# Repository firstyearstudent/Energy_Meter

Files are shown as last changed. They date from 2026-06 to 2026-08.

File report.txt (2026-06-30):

Info: Processing symbol 'J2:Connector_PinHeader_2.54mm:PinHeader_1x04_P2.54mm_Horizontal'.
Info: Processing symbol 'TP8:PCM_SparkFun-Connector:TestPoint-0.5mm'.
Info: Processing symbol 'C11:Capacitor_THT:CP_Radial_D5.0mm_P2.00mm'.
Info: Processing symbol 'R19:Components_Footprint:RES_ERA8ARB203V'.
Info: Processing symbol 'R4:PCM_SparkFun-Resistor:R_0603_1608Metric'.
Info: Processing symbol 'C30:Capacitor_THT:C_Disc_D5.0mm_W2.5mm_P2.50mm'.
Info: Processing symbol 'R34:PCM_SparkFun-Resistor:R_0603_1608Metric'.
Info: Processing symbol 'C12:PCM_4ms_Capacitor:C_0603'.
Info: Processing symbol 'TP9:PCM_SparkFun-Connector:TestPoint-0.5mm'.
Info: Processing symbol 'R20:Components_Footprint:RES_ERA8ARB203V'.
Info: Processing symbol 'R3:Resistor_SMD:R_1206_3216Metric'.
Info: Processing symbol 'C31:Capacitor_THT:C_Disc_D5.0mm_W2.5mm_P2.50mm'.
Info: Processing symbol 'C13:Capacitor_SMD:C_0603_1608Metric'.
Info: Processing symbol 'C29:Capacitor_THT:C_Disc_D5.0mm_W2.5mm_P2.50mm'.
Info: Processing symbol 'TP10:PCM_SparkFun-Connector:TestPoint-0.5mm'.
Info: Processing symbol 'R21:Components_Footprint:RES_ERA8ARB203V'.
Info: Processing symbol 'R2:Resistor_SMD:R_1206_3216Metric'.
Info: Processing symbol 'R33:Resistor_THT:R_Axial_DIN0207_L6.3mm_D2.5mm_P10.16mm_Horizontal'.
Info: Processing symbol 'C14:PCM_SparkFun-Capacitor:C_0603_1608Metric'.
Info: Processing symbol 'C28:Capacitor_THT:C_Disc_D5.0mm_W2.5mm_P2.50mm'.
Info: Processing symbol 'R22:Resistor_THT:R_Axial_DIN0207_L6.3mm_D2.5mm_P10.16mm_Horizontal'.
Info: Processing symbol 'C9:Capacitor_THT:CP_Radial_D5.0mm_P2.00mm'.
Info: Processing symbol 'R16:Components_Footprint:RES_ERA8ARB203V'.
Info: Processing symbol 'U3:Package_SO:SOIC-16_3.9x9.9mm_P1.27mm'.
Info: Processing symbol 'C8:Capacitor_THT:CP_Radial_D5.0mm_P2.00mm'.
Info: Processing symbol 'R6:PCM_fab:R_1206'.
Info: Processing symbol 'C33:Components_Footprint:CAPRB250W50L400T250H550'.
Info: Processing symbol 'TP6:PCM_SparkFun-Connector:TestPoint-0.5mm'.
Info: Processing symbol 'SW2:PCM_fab:Button_CnK_PTS636.0_6x3.5mm'.
Info: Processing symbol 'R17:Components_Footprint:RES_ERA8ARB203V'.
Info: Processing symbol 'FB1:PCM_Ferrite_SMD_AKL:Ferrite_0805_2012Metric'.
Info: Processing symbol 'TP11:PCM_SparkFun-Connector:TestPoint-0.5mm'.
Info: Processing symbol 'R5:PCM_SparkFun-Resistor:R_1206_3216Metric'.
Info: Processing symbol 'U2:Package_SO:TSSOP-10_3x3mm_P0.5mm'.
Info: Processing symbol 'C32:Capacitor_THT:C_Disc_D5.0mm_W2.5mm_P2.50mm'.
Info: Processing symbol 'TP7:PCM_SparkFun-Connector:TestPoint-0.5mm'.
Info: Processing symbol 'C10:Capacitor_THT:C_Disc_D5.0mm_W2.5mm_P2.50mm'.
Info: Processing symbol 'R18:Components_Footprint:RES_ERA8ARB203V'.
Info: Processing symbol 'SW1:Button_Switch_SMD:SW_Tactile_SPST_NO_Straight_CK_PTS636Sx25SMTRLFS'.
Info: Processing symbol 'R4_Burden1:Components_Footprint:RESC3116X65N'.
Info: Processing symbol 'J1:PCM_fab:Conn_Jack_Stereo_3.5mm_CUI_SJ-3523-SMT-TR'.
Info: Processing symbol 'J7:Components_Footprint:POMONA_73096-2'.
Info: Processing symbol 'R25:Capacitor_SMD:C_0603_1608Metric'.
Info: Processing symbol 'J8:Components_Footprint:POMONA_73096-2'.
Info: Processing symbol 'TP14:PCM_SparkFun-Connector:TestPoint-0.5mm'.
Info: Processing symbol 'TP19:PCM_SparkFun-Connector:TestPoint-0.5mm'.
Info: Processing symbol 'R30:Resistor_THT:R_Axial_DIN0207_L6.3mm_D2.5mm_P10.16mm_Horizontal'.
Info: Processing symbol 'C19:Capacitor_SMD:C_0603_1608Metric'.
Info: Processing symbol 'J5:Components_Footprint:POMONA_73096-2'.
Info: Processing symbol 'C23:Capacitor_THT:C_Disc_D5.0mm_W2.5mm_P2.50mm'.
Info: Processing symbol 'R26:Resistor_THT:R_Axial_DIN0207_L6.3mm_D2.5mm_P10.16mm_Horizontal'.
Info: Processing symbol 'TP18:PCM_SparkFun-Connector:TestPoint-0.5mm'.
Info: Processing symbol 'C24:Capacitor_THT:CP_Radial_D5.0mm_P2.00mm'.
Info: Processing symbol 'C20:Capacitor_SMD:C_0603_1608Metric'.
Info: Processing symbol 'TP15:PCM_SparkFun-Connector:TestPoint-0.5mm'.
Info: Processing symbol 'R29:Resistor_THT:R_Axial_DIN0207_L6.3mm_D2.5mm_P10.16mm_Horizontal'.
Info: Processing symbol 'TP17:PCM_SparkFun-Connector:TestPoint-0.5mm'.
Info: Processing symbol 'C22:Capacitor_SMD:C_0603_1608Metric'.
Info: Processing symbol 'R27:Resistor_THT:R_Axial_DIN0207_L6.3mm_D2.5mm_P10.16mm_Horizontal'.
Info: Processing symbol 'C21:Capacitor_SMD:C_0603_1608Metric'.
Info: Processing symbol 'TP16:PCM_SparkFun-Connector:TestPoint-0.5mm'.
Info: Processing symbol 'J6:Components_Footprint:POMONA_73096-2'.
Info: Processing symbol 'C16:Capacitor_SMD:C_0603_1608Metric'.
Info: Processing symbol 'R1:Resistor_SMD:R_1206_3216Metric'.
Info: Processing symbol 'J3:PCM_SparkFun-Connector:USB-C_16'.
Info: Processing symbol 'C15:Capacitor_SMD:C_0603_1608Metric'.
Info: Processing symbol 'R32:PCM_SparkFun-Resistor:R_0603_1608Metric'.
Info: Processing symbol 'C26:Capacitor_THT:C_Disc_D5.0mm_W2.5mm_P2.50mm'.
Info: Processing symbol 'U1:Package_QFP:LQFP-48_7x7mm_P0.5mm'.
Info: Processing symbol 'R23:Resistor_THT:R_Axial_DIN0207_L6.3mm_D2.5mm_P10.16mm_Horizontal'.
Info: Processing symbol 'L1:Inductor_SMD:L_Sunlord_SWPA6028S'.
Info: Processing symbol 'TP12:PCM_SparkFun-Connector:TestPoint-0.5mm'.
Info: Processing symbol 'C1:Capacitor_SMD:C_1206_3216Metric'.
Info: Processing symbol 'TP21:PCM_SparkFun-Connector:TestPoint-0.5mm'.
Info: Processing symbol 'C25:Capacitor_THT:C_Disc_D5.0mm_W2.5mm_P2.50mm'.
Info: Processing symbol 'R24:Resistor_THT:R_Axial_DIN0207_L6.3mm_D2.5mm_P10.16mm_Horizontal'.
Info: Processing symbol 'J9:PCM_SparkFun-Connector:ScrewTerminal_1x02_P3.5mm_Horizontal_Black'.
Info: Processing symbol 'C17:Capacitor_SMD:C_0603_1608Metric'.
Info: Processing symbol 'R31:Resistor_THT:R_Axial_DIN0207_L6.3mm_D2.5mm_P10.16mm_Horizontal'.
Info: Processing symbol 'TP13:PCM_SparkFun-Connector:TestPoint-0.5mm'.
Info: Processing symbol 'TP20:PCM_SparkFun-Connector:TestPoint-0.5mm'.
Info: Processing symbol 'C18:Capacitor_SMD:C_0603_1608Metric'.
Info: Processing symbol 'TP4:PCM_SparkFun-Connector:TestPoint-0.5mm'.
Info: Processing symbol 'T1:Components_Footprint:XFMR_ZMPT101B'.
Info: Processing symbol 'R15_Shunt1:Components_Footprint:RESC6331X88N'.
Info: Processing symbol 'R11:PCM_SparkFun-Resistor:R_0603_1608Metric'.
Info: Processing symbol 'D6:PCM_Diode_SMD_AKL:D_SOD-523'.
Info: Processing symbol 'Y1:Crystal:Crystal_HC49-4H_Vertical'.
Info: Processing symbol 'TP1:PCM_SparkFun-Connector:TestPoint-0.5mm'.
Info: Processing symbol 'C2:Capacitor_SMD:C_1206_3216Metric'.
Info: Processing symbol 'C6:Capacitor_SMD:C_1206_3216Metric'.
Info: Processing symbol 'U4:Package_TO_SOT_SMD:SOT-223-3_TabPin2'.
Info: Processing symbol 'R8:Resistor_THT:R_Axial_DIN0207_L6.3mm_D2.5mm_P10.16mm_Horizontal'.
Info: Processing symbol 'TP2:PCM_SparkFun-Connector:TestPoint-0.5mm'.
Info: Processing symbol 'TP3:PCM_SparkFun-Connector:TestPoint-0.5mm'.
Info: Processing symbol 'C3:Capacitor_SMD:C_1206_3216Metric'.
Info: Processing symbol 'D1:LED_SMD:LED_1206_3216Metric'.
Info: Processing symbol 'D3:LED_SMD:LED_1206_3216Metric'.
Info: Processing symbol 'R13:PCM_SparkFun-Resistor:R_0603_1608Metric'.
Info: Processing symbol 'R9:Resistor_THT:R_Axial_DIN0207_L6.3mm_D2.5mm_P10.16mm_Horizontal'.
Info: Processing symbol 'SW4:Components_Footprint:EC11E15244G1_AAL'.
Info: Processing symbol 'R10_Burden1:Components_Footprint:RESC2012X60N'.
Info: Processing symbol 'C5:PCM_SparkFun-Capacitor:C_1210_3225Metric'.
Info: Processing symbol 'R15:Resistor_THT:R_Axial_DIN0207_L6.3mm_D2.5mm_P10.16mm_Horizontal'.
Info: Processing symbol 'DS1:Components_Footprint:MODULE_4311'.
Info: Processing symbol 'SW5:Button_Switch_THT:SW_PUSH_6mm'.
Info: Processing symbol 'R10:PCM_SparkFun-Resistor:R_0603_1608Metric'.
Info: Processing symbol 'C4:Capacitor_SMD:C_1206_3216Metric'.
Info: Processing symbol 'SW3:Button_Switch_THT:SW_Slide_SPDT_Straight_CK_OS102011MS2Q'.
Info: Processing symbol 'R14:PCM_SparkFun-Resistor:R_1206_3216Metric'.
Info: Processing symbol 'C7:Capacitor_SMD:C_1206_3216Metric'.
Info: Processing symbol 'R7:Resistor_THT:R_Axial_DIN0207_L6.3mm_D2.5mm_P10.16mm_Horizontal'.
Info: Processing symbol 'TP5:PCM_SparkFun-Connector:TestPoint-0.5mm'.
Info: Processing symbol 'D2:LED_SMD:LED_1206_3216Metric'.
Info: Processing symbol 'C35:Components_Footprint:CAPRB250W50L400T250H550'.
Info: Processing symbol 'D4:LED_SMD:LED_1206_3216Metric'.
Info: Processing symbol 'U6:Components_Footprint:SOP127P600X165-9N'.
Info: Processing symbol 'D7:PCM_Diode_SMD_AKL:D_SOD-523'.
Info: Processing symbol 'R12:PCM_SparkFun-Resistor:R_0603_1608Metric'.
Updated R31 sheetfile to 'Energy_Meter.kicad_sch'.
Updated SW5 symbol association from  to /096593e3-2328-43b2-82fb-24280b29d08e.
Updated R30 footprint filters to 'Resistor_THT:R_Axial_DIN0207_L6.3mm_D2.5mm*'.
Updated R31 unit metadata.
Connected SW4 pin C to GND.
Connected R31 pin 1 to 3.3VD.
Connected R30 pin 2 to Net-(C28-Pad2).
Connected SW4 pin E to GND.
Connected R30 pin 1 to 3.3VD.
Updated SW4 unit metadata.
Updated R31 footprint filters to 'Resistor_THT:R_Axial_DIN0207_L6.3mm_D2.5mm*'.
Updated R30 unit metadata.
Updated R31 sheetname to '/'.
Changed SW5 value from SW_PUSH_6mm to Push_Button.
Updated R31 fields.
Updated R31 symbol association from  to /9017e46f-2ed7-42f1-b664-4ba9339a6ba1.
Changed REF** reference designator to SW5.
Added R31 (footprint 'Resistor_THT:R_Axial_DIN0207_L6.3mm_D2.5mm_P10.16mm_Horizontal').
Changed REF** reference designator to R30.
Changed REF** reference designator to R31.
Changed R31 value from R_Axial_DIN0207_L6.3mm_D2.5mm_P10.16mm_Horizontal to 10k.
Connected R31 pin 2 to Net-(C30-Pad2).
Added SW5 (footprint 'Button_Switch_THT:SW_PUSH_6mm').
Add net Net-(U1-PB2).
Updated R29 fields.
Updated R29 symbol association from  to /d3790d62-b8e2-4885-a9b2-6dcfec7a4e3b.
Updated SW5 unit metadata.
Changed R29 value from R_Axial_DIN0207_L6.3mm_D2.5mm_P10.16mm_Horizontal to 10k.
Changed REF** reference designator to R29.
Added R29 (footprint 'Resistor_THT:R_Axial_DIN0207_L6.3mm_D2.5mm_P10.16mm_Horizontal').
Updated R27 unit metadata.
Connected R27 pin 2 to Net-(U1-PB2).
Added T1 (footprint 'Components_Footprint:XFMR_ZMPT101B').
Updated R29 sheetname to '/'.
Changed REF** reference designator to T1.
Changed T1 value from XFMR_ZMPT101B to ZMPT101B.
Connected R27 pin 1 to GND.
Updated R27 footprint filters to 'Resistor_THT:R_Axial_DIN0207_L6.3mm_D2.5mm*'.
Updated R27 sheetfile to 'Energy_Meter.kicad_sch'.
Updated R11 footprint filters to 'R_*'.
Updated R27 sheetname to '/'.
Updated T1 symbol association from  to /87a0423d-53e1-46c7-bd90-0382405e7eaa.
Connected SW5 pin 2 to Net-(C31-Pad2).
Updated R30 sheetname to '/'.
Updated R30 fields.
Updated R30 symbol association from  to /a338d966-6925-4aad-8e60-40405d52ac68.
Updated SW5 fields.
Updated SW5 sheetname to '/'.
Changed R30 value from R_Axial_DIN0207_L6.3mm_D2.5mm_P10.16mm_Horizontal to 10k.
Updated R32 sheetname to '/'.
Updated SW5 sheetfile to 'Energy_Meter.kicad_sch'.
Added R30 (footprint 'Resistor_THT:R_Axial_DIN0207_L6.3mm_D2.5mm_P10.16mm_Horizontal').
Updated R30 sheetfile to 'Energy_Meter.kicad_sch'.
Connected SW5 pin 1 to GND.
Connected SW5 pin 2 to Net-(C31-Pad2).
Updated R29 unit metadata.
Connected R29 pin 1 to 3.3VD.
Connected SW5 pin 1 to GND.
Connected R29 pin 2 to Net-(C29-Pad2).
Updated R29 footprint filters to 'Resistor_THT:R_Axial_DIN0207_L6.3mm_D2.5mm*'.
Updated R29 sheetfile to 'Energy_Meter.kicad_sch'.
Connected SW3 pin 2 to Net-(SW3-B).
Updated SW3 fields.
Updated SW1 sheetname to '/'.
Updated SW3 sheetname to '/'.
Updated SW1 fields.
Updated SW1 symbol association from  to /d2a9903d-55e1-423c-93b8-542035d82c9e.
Changed SW1 value from SW_Tactile_SPST_NO_Straight_CK_PTS636Sx25SMTRLFS to SW_Push.
Changed REF** reference designator to SW1.
Added SW1 (footprint 'Button_Switch_SMD:SW_Tactile_SPST_NO_Straight_CK_PTS636Sx25SMTRLFS').
Updated SW3 sheetfile to 'Energy_Meter.kicad_sch'.
Updated SW3 symbol association from  to /7dab059d-c71f-4d2d-af27-36c57973f747.
Updated R34 unit metadata.
Connected SW3 pin 1 to GND.
Connected R34 pin 1 to Net-(C31-Pad2).
Connected SW3 pin 3 to 3.3VD.
Connected R34 pin 2 to /RANGE.
Add net /RANGE.
Updated R34 footprint filters to 'R_*'.
Updated R34 sheetfile to 'Energy_Meter.kicad_sch'.
Updated R34 sheetname to '/'.
Added SW2 (footprint 'PCM_fab:Button_CnK_PTS636.0_6x3.5mm').
Updated SW2 footprint filters to '*Button?CnK*'.
Connected SW2 pin 2 to /TFT_RST.
Updated SW2 unit metadata.
Updated SW2 sheetfile to 'Energy_Meter.kicad_sch'.
Updated SW2 sheetname to '/'.
Updated SW2 fields.
Updated SW2 symbol association from  to /22db1ad1-a794-487a-9f3f-db319c2bdb46.
Changed SW2 value from Button_CnK_PTS636.0_6x3.5mm to Switch_Tactile_CnK.
Changed REF** reference designator to SW2.
Updated SW3 unit metadata.
Updated SW1 unit metadata.
Connected SW1 pin 1 to GND.
Added SW3 (footprint 'Button_Switch_THT:SW_Slide_SPDT_Straight_CK_OS102011MS2Q').
Changed REF** reference designator to SW3.
Connected SW1 pin 2 to Net-(U6-KEY).
Changed SW3 value from SW_Slide_SPDT_Straight_CK_OS102011MS2Q to SW_SPDT.
Add net Net-(U6-KEY).
Updated SW1 sheetfile to 'Energy_Meter.kicad_sch'.
Updated R32 footprint filters to 'R_*'.
Updated SW4 sheetname to '/'.
Changed REF** reference designator to R33.
Added R33 (footprint 'Resistor_THT:R_Axial_DIN0207_L6.3mm_D2.5mm_P10.16mm_Horizontal').
Updated SW4 sheetfile to 'Energy_Meter.kicad_sch'.
Updated R32 unit metadata.
Connected R32 pin 2 to /PUSH.
Updated SW4 footprint filters to 'EC11E15244G1_AAL'.
Add net /PUSH.
Connected R32 pin 1 to Net-(C30-Pad2).
Changed R33 value from R_Axial_DIN0207_L6.3mm_D2.5mm_P10.16mm_Horizontal to 10k.
Updated R32 sheetfile to 'Energy_Meter.kicad_sch'.
Connected SW4 pin B to Net-(C28-Pad2).
Connected SW2 pin 1 to GND.
Connected SW4 pin D to Net-(C30-Pad2).
Updated R32 fields.
Updated R32 symbol association from  to /95be6e3a-ffd1-4b5c-a334-f7b902966ed1.
Changed R32 value from R_0603_1608Metric to 100.
Connected SW4 pin A to Net-(C29-Pad2).
Changed REF** reference designator to R32.
Connected R33 pin 1 to 3.3VD.
Updated R34 fields.
Updated R34 symbol association from  to /fe889133-f561-4d1c-9acb-53b2d3170c92.
Changed R34 value from R_0603_1608Metric to 100.
Changed REF** reference designator to R34.
Added R34 (footprint 'PCM_SparkFun-Resistor:R_0603_1608Metric').
Added SW4 (footprint 'Components_Footprint:EC11E15244G1_AAL').
Changed REF** reference designator to SW4.
Updated R33 unit metadata.
Connected R33 pin 2 to Net-(C31-Pad2).
Added R32 (footprint 'PCM_SparkFun-Resistor:R_0603_1608Metric').
Updated R33 footprint filters to 'Resistor_THT:R_Axial_DIN0207_L6.3mm_D2.5mm*'.
Changed SW4 value from EC11E15244G1_AAL to EC11E15244G1.
Updated R33 sheetfile to 'Energy_Meter.kicad_sch'.
Updated R33 sheetname to '/'.
Updated R33 fields.
Updated SW4 symbol association from  to /1b6d3bd7-2777-49fa-b441-ffda2d95eb1e.
Updated R33 symbol association from  to /6c129086-1558-4fe3-90ed-3d314c50f6ce.
Updated SW4 fields.
Updated R15_Shunt1 sheetfile to 'Energy_Meter.kicad_sch'.
Add net Net-(R16-Pad2).
Updated R16 sheetfile to 'Energy_Meter.kicad_sch'.
Updated R16 sheetname to '/'.
Updated R16 fields.
Updated R16 symbol association from  to /d24ec295-7454-4889-8fb5-7ec9d18e970f.
Changed R16 value from RES_ERA8ARB203V to 20k_1206.
Changed REF** reference designator to R16.
Added R16 (footprint 'Components_Footprint:RES_ERA8ARB203V').
Updated R15_Shunt1 unit metadata.
Connected R15_Shunt1 pin 2 to Net-(R15_Shunt1-Pad2).
Connected R15_Shunt1 pin 1 to Net-(R14-Pad1).
Connected R16 pin 2 to Net-(R16-Pad2).
Updated R15_Shunt1 sheetname to '/'.
Updated R15_Shunt1 fields.
Updated R15_Shunt1 symbol association from  to /1717d047-043e-4354-aeb3-5077f84d7610.
Changed R15_Shunt1 value from RESC6331X88N to 0.001_1%_5W.
Changed REF** reference designator to R15_Shunt1.
Added R15_Shunt1 (footprint 'Components_Footprint:RESC6331X88N').
Updated R15 unit metadata.
Connected R15 pin 2 to /TFT_RST.
Connected R15 pin 1 to 3.3VD.
Updated R15 footprint filters to 'Resistor_THT:R_Axial_DIN0207_L6.3mm_D2.5mm*'.
Updated R15 sheetfile to 'Energy_Meter.kicad_sch'.
Connected R17 pin 1 to Net-(R17-Pad1).
Add net Net-(R18-Pad1).
Updated R18 sheetfile to 'Energy_Meter.kicad_sch'.
Updated R18 sheetname to '/'.
Updated R18 fields.
Updated R18 symbol association from  to /605f97b5-5b5a-45ac-96c2-aa8f0f7967b4.
Changed R18 value from RES_ERA8ARB203V to 20k_1206.
Changed REF** reference designator to R18.
Added R18 (footprint 'Components_Footprint:RES_ERA8ARB203V').
Updated R17 unit metadata.
Connected R17 pin 2 to Net-(R17-Pad2).
Add net Net-(R17-Pad2).
Updated R15 sheetname to '/'.
Add net Net-(R17-Pad1).
Updated R17 sheetfile to 'Energy_Meter.kicad_sch'.
Updated R17 sheetname to '/'.
Updated R17 fields.
Updated R17 symbol association from  to /32fd0044-c9a3-4c71-b9f6-3ce80c732c5d.
Changed R17 value from RES_ERA8ARB203V to 20k_1206.
Changed REF** reference designator to R17.
Added R17 (footprint 'Components_Footprint:RES_ERA8ARB203V').
Updated R16 unit metadata.
Connected R16 pin 1 to Net-(R16-Pad1).
Add net Net-(R16-Pad1).
Updated R12 sheetfile to 'Energy_Meter.kicad_sch'.
Updated R13 sheetname to '/'.
Updated R13 fields.
Updated R13 symbol association from  to /a9d84476-be1f-4ca3-b1ae-a8ff1df09574.
Changed R13 value from R_0603_1608Metric to 4.7k.
Changed REF** reference designator to R13.
Added R13 (footprint 'PCM_SparkFun-Resistor:R_0603_1608Metric').
Updated R12 unit metadata.
Connected R12 pin 2 to 3.3VD.
Connected R12 pin 1 to /SCL1.
Add net /SCL1.
Updated R12 footprint filters to 'R_*'.
Updated R13 sheetfile to 'Energy_Meter.kicad_sch'.
Updated R12 sheetname to '/'.
Updated R12 fields.
Updated R12 symbol association from  to /bd37f52b-9bcc-4cde-a85c-7b5f85427732.
Changed R12 value from R_0603_1608Metric to 4.7k.
Changed REF** reference designator to R12.
Added R12 (footprint 'PCM_SparkFun-Resistor:R_0603_1608Metric').
Updated R11 unit metadata.
Connected R11 pin 2 to 3.3VD.
Connected R11 pin 1 to /SDA1.
Add net /SDA1.
Added C1 (footprint 'Capacitor_SMD:C_1206_3216Metric').
Updated R14 sheetname to '/'.
Updated R15 fields.
Updated R15 symbol association from  to /f953d1ff-95f0-4f80-b716-6e3cc526713e.
Changed R15 value from R_Axial_DIN0207_L6.3mm_D2.5mm_P10.16mm_Horizontal to 10k.
Changed REF** reference designator to R15.
Added R15 (footprint 'Resistor_THT:R_Axial_DIN0207_L6.3mm_D2.5mm_P10.16mm_Horizontal').
Updated R14 unit metadata.
Connected R14 pin 1 to Net-(R14-Pad1).
Add net Net-(R14-Pad1).
Connected R14 pin 2 to IN-.
Updated R14 footprint filters to 'R_*'.
Updated R14 sheetfile to 'Energy_Meter.kicad_sch'.
Connected R18 pin 1 to Net-(R18-Pad1).
Updated R14 fields.
Updated R14 symbol association from  to /2ae87468-ac1b-4ef5-84e0-95d33e6e152b.
Changed R14 value from R_1206_3216Metric to 10.
Changed REF** reference designator to R14.
Added R14 (footprint 'PCM_SparkFun-Resistor:R_1206_3216Metric').
Updated R13 unit metadata.
Connected R13 pin 2 to Net-(U2-~{Alert}).
Add net Net-(U2-~{Alert}).
Connected R13 pin 1 to 3.3VD.
Updated R13 footprint filters to 'R_*'.
Updated R24 symbol association from  to /e59756a2-65bf-43f8-a926-fd39bd42aaef.
Updated R25 symbol association from  to /0994b7eb-327d-4d68-92b8-b3a5f0d73b3e.
Changed R25 value from C_0603_1608Metric to 1.5k_0603.
Changed REF** reference designator to R25.
Added R25 (footprint 'Capacitor_SMD:C_0603_1608Metric').
Updated R24 unit metadata.
Connected R24 pin 2 to ADC2.
Connected R24 pin 1 to Net-(R24-Pad1).
Updated R24 footprint filters to 'Resistor_THT:R_Axial_DIN0207_L6.3mm_D2.5mm*'.
Updated R24 sheetfile to 'Energy_Meter.kicad_sch'.
Updated R24 sheetname to '/'.
Updated R24 fields.
Updated R25 fields.
Changed R24 value from R_Axial_DIN0207_L6.3mm_D2.5mm_P10.16mm_Horizontal to 1k.
Changed REF** reference designator to R24.
Added R24 (footprint 'Resistor_THT:R_Axial_DIN0207_L6.3mm_D2.5mm_P10.16mm_Horizontal').
Updated R23 unit metadata.
Connected R23 pin 2 to Net-(C11-Pad1).
Connected R23 pin 1 to GND.
Updated R23 footprint filters to 'Resistor_THT:R_Axial_DIN0207_L6.3mm_D2.5mm*'.
Updated R23 sheetfile to 'Energy_Meter.kicad_sch'.
Updated R23 sheetname to '/'.
Updated R23 fields.
Updated R23 symbol association from  to /1a486011-ce61-4140-aede-66c9c4201624.
Updated R26 sheetname to '/'.
Updated R27 symbol association from  to /33faaad6-cd61-4112-8381-fef5d32c65cc.
Changed R27 value from R_Axial_DIN0207_L6.3mm_D2.5mm_P10.16mm_Horizontal to 10k.
Changed REF** reference designator to R27.
Added R27 (footprint 'Resistor_THT:R_Axial_DIN0207_L6.3mm_D2.5mm_P10.16mm_Horizontal').
Updated R26 unit metadata.
Connected R26 pin 1 to Net-(SW3-B).
Add net Net-(SW3-B).
Connected R26 pin 2 to Net-(U1-BOOT0).
Add net Net-(U1-BOOT0).
Updated R26 footprint filters to 'Resistor_THT:R_Axial_DIN0207_L6.3mm_D2.5mm*'.
Updated R26 sheetfile to 'Energy_Meter.kicad_sch'.
Changed R23 value from R_Axial_DIN0207_L6.3mm_D2.5mm_P10.16mm_Horizontal to 470k.
Updated R26 fields.
Updated R26 symbol association from  to /bc311083-1da1-4910-a27b-add62fe090ba.
Changed R26 value from R_Axial_DIN0207_L6.3mm_D2.5mm_P10.16mm_Horizontal to 10k.
Changed REF** reference designator to R26.
Added R26 (footprint 'Resistor_THT:R_Axial_DIN0207_L6.3mm_D2.5mm_P10.16mm_Horizontal').
Updated R25 unit metadata.
Connected R25 pin 2 to /USB_C+.
Connected R25 pin 1 to 3.3VD.
Updated R25 footprint filters to 'R_* R_*'.
Updated R25 sheetfile to 'Energy_Meter.kicad_sch'.
Updated R25 sheetname to '/'.
Connected R19 pin 2 to Net-(R17-Pad1).
Updated R20 unit metadata.
Connected R20 pin 1 to AC_L.
Connected R20 pin 2 to Net-(R18-Pad1).
Updated R20 sheetfile to 'Energy_Meter.kicad_sch'.
Updated R20 sheetname to '/'.
Updated R20 fields.
Updated R20 symbol association from  to /97534cb9-37e9-4301-bd6c-4e8089e2042e.
Changed R20 value from RES_ERA8ARB203V to 20k_1206.
Changed REF** reference designator to R20.
Added R20 (footprint 'Components_Footprint:RES_ERA8ARB203V').
Updated R19 unit metadata.
Added R21 (footprint 'Components_Footprint:RES_ERA8ARB203V').
Connected R19 pin 1 to Net-(R19-Pad1).
Add net Net-(R19-Pad1).
Updated R19 sheetfile to 'Energy_Meter.kicad_sch'.
Updated R19 sheetname to '/'.
Updated R19 fields.
Updated R19 symbol association from  to /00628b0d-4290-42c4-81c8-926ae012639d.
Changed R19 value from RES_ERA8ARB203V to 20k_1206.
Changed REF** reference designator to R19.
Added R19 (footprint 'Components_Footprint:RES_ERA8ARB203V').
Updated R18 unit metadata.
Connected R18 pin 2 to Net-(R16-Pad1).
Changed REF** reference designator to R22.
Changed REF** reference designator to R23.
Added R23 (footprint 'Resistor_THT:R_Axial_DIN0207_L6.3mm_D2.5mm_P10.16mm_Horizontal').
Updated R22 unit metadata.
Connected R22 pin 2 to 3.3VA.
Connected R22 pin 1 to Net-(C11-Pad1).
Updated R22 footprint filters to 'Resistor_THT:R_Axial_DIN0207_L6.3mm_D2.5mm*'.
Updated R22 sheetfile to 'Energy_Meter.kicad_sch'.
Updated R22 sheetname to '/'.
Updated R22 fields.
Updated R22 symbol association from  to /ea44b6a0-05e6-4ffd-a8ec-0865228f4b2b.
Changed R22 value from R_Axial_DIN0207_L6.3mm_D2.5mm_P10.16mm_Horizontal to 470k.
Updated R27 fields.
Added R22 (footprint 'Resistor_THT:R_Axial_DIN0207_L6.3mm_D2.5mm_P10.16mm_Horizontal').
Updated R21 unit metadata.
Connected R21 pin 2 to Net-(R19-Pad1).
Connected R21 pin 1 to AC_N.
Updated R21 sheetfile to 'Energy_Meter.kicad_sch'.
Updated R21 sheetname to '/'.
Updated R21 fields.
Updated R21 symbol association from  to /6555944e-b537-475b-9d69-0d5021b60e56.
Changed R21 value from RES_ERA8ARB203V to 20k_1206.
Changed REF** reference designator to R21.
Connected U1 pin 40 to unconnected-(U1-PB4-Pad40).
Connected U1 pin 33 to /USB_C+.
Connected U1 pin 37 to /SWCLK.
Connected U1 pin 29 to /RANGE.
Connected U1 pin 11 to ADC2.
Connected U1 pin 21 to /SCL2.
Add net /SCL2.
Connected U1 pin 46 to /TFT_DC.
Connected U1 pin 23 to GND.
Connected U1 pin 35 to GND.
Connected U1 pin 5 to /HSE_IN.
Connected U1 pin 9 to 3.3VA.
Connected U1 pin 36 to 3.3VD.
Add net unconnected-(U1-PB4-Pad40).
Connected U1 pin 22 to /SDA2.
Add net /SDA2.
Connected U1 pin 25 to /PUSH.
Connected U1 pin 8 to GND.
Connected U1 pin 38 to unconnected-(U1-PA15-Pad38).
Add net unconnected-(U1-PA15-Pad38).
Connected U1 pin 45 to /TFT_CS.
Connected U1 pin 27 to /TFT_MISO.
Connected U1 pin 18 to unconnected-(U1-PB0-Pad18).
Add net unconnected-(U1-PB0-Pad18).
Add net unconnected-(U1-PA5-Pad15).
Connected U1 pin 20 to Net-(U1-PB2).
Connected U1 pin 19 to /TFT_BLK.
Connected U1 pin 13 to unconnected-(U1-PA3-Pad13).
Add net unconnected-(U1-PA3-Pad13).
Connected U1 pin 14 to unconnected-(U1-PA4-Pad14).
Add net unconnected-(U1-PA4-Pad14).
Connected U1 pin 16 to /EC_A.
Connected U1 pin 39 to unconnected-(U1-PB3-Pad39).
Add net unconnected-(U1-PB3-Pad39).
Connected U1 pin 17 to /EC_B.
Connected U1 pin 15 to unconnected-(U1-PA5-Pad15).
Connected U1 pin 47 to GND.
Connected U1 pin 42 to /SCL1.
Connected U1 pin 34 to /SWDIO.
Connected U1 pin 1 to 3.3VD.
Connected U1 pin 48 to 3.3VD.
Connected U1 pin 7 to /TFT_RST.
Connected U1 pin 41 to unconnected-(U1-PB5-Pad41).
Add net unconnected-(U1-PB5-Pad41).
Connected U1 pin 3 to unconnected-(U1-PC14-Pad3).
Add net unconnected-(U1-PC14-Pad3).
Connected U1 pin 6 to /HSE_OUT.
Connected U1 pin 31 to /RX.
Updated TP20 sheetname to '/'.
Updated TP21 sheetname to '/'.
Updated TP21 fields.
Updated TP21 symbol association from  to /1e7c1d3b-36c7-48c4-9730-2af50b370269.
Changed TP21 value from Val** to 0.5mm.
Changed Ref** reference designator to TP21.
Added TP21 (footprint 'PCM_SparkFun-Connector:TestPoint-0.5mm').
Updated TP20 unit metadata.
Connected TP20 pin 1 to /TX.
Add net /TX.
Updated TP20 footprint filters to 'Pin* Test*'.
Updated TP20 sheetfile to 'Energy_Meter.kicad_sch'.
Updated TP21 sheetfile to 'Energy_Meter.kicad_sch'.
Updated TP20 fields.
Updated TP20 symbol association from  to /76657602-98e6-4308-94ad-b37e04be31d4.
Changed TP20 value from Val** to 0.5mm.
Changed Ref** reference designator to TP20.
Added TP20 (footprint 'PCM_SparkFun-Connector:TestPoint-0.5mm').
Updated TP19 unit metadata.
Connected TP19 pin 1 to /RX.
Add net /RX.
Updated TP19 footprint filters to 'Pin* Test*'.
Updated TP19 sheetfile to 'Energy_Meter.kicad_sch'.
Updated TP19 sheetname to '/'.
Connected U1 pin 10 to ADC1.
Connected U1 pin 32 to /USB_C-.
Connected U1 pin 24 to 3.3VD.
Connected U1 pin 26 to /TFT_SCK.
Connected U1 pin 44 to Net-(U1-BOOT0).
Connected U1 pin 4 to unconnected-(U1-PC15-Pad4).
Add net unconnected-(U1-PC15-Pad4).
Connected U1 pin 12 to unconnected-(U1-PA2-Pad12).
Add net unconnected-(U1-PA2-Pad12).
Connected U1 pin 2 to unconnected-(U1-PC13-Pad2).
Add net unconnected-(U1-PC13-Pad2).
Connected U1 pin 43 to /SDA1.
Connected U1 pin 28 to /TFT_MOSI.
Updated U1 footprint filters to 'LQFP*7x7mm*P0.5mm*'.
Updated U1 sheetfile to 'Energy_Meter.kicad_sch'.
Updated U1 sheetname to '/'.
Updated U1 fields.
Updated U1 symbol association from  to /df958145-98bf-4436-b8b1-3f5ec85b5816.
Changed U1 value from LQFP-48_7x7mm_P0.5mm to STM32F103C8Tx.
Changed REF** reference designator to U1.
Added U1 (footprint 'Package_QFP:LQFP-48_7x7mm_P0.5mm').
Updated TP21 unit metadata.
Connected TP21 pin 1 to GND.
Updated TP21 footprint filters to 'Pin* Test*'.
Updated U4 fields.
Changed U6 value from SOP127P600X165-9N to IP5306.
Changed REF** reference designator to U6.
Added U6 (footprint 'Components_Footprint:SOP127P600X165-9N').
Updated U4 unit metadata.
Connected U4 pin 3 to 5V.
Connected U4 pin 1 to GND.
Connected U4 pin 2 to 3.3VD.
Connected U4 pin 2 to 3.3VD.
Updated U4 footprint filters to 'SOT?223*TabPin2*'.
Updated U4 sheetfile to 'Energy_Meter.kicad_sch'.
Updated U4 sheetname to '/'.
Updated U6 symbol association from  to /7fd59a5a-0f41-42be-88ef-e285028ba740.
Updated U4 symbol association from  to /fbf2f771-70e9-40ec-9f3e-84057b3e04ba.
Changed U4 value from SOT-223-3_TabPin2 to AMS1117-3.3.
Changed REF** reference designator to U4.
Added U4 (footprint 'Package_TO_SOT_SMD:SOT-223-3_TabPin2').
Updated U3 unit metadata.
Connected U3 pin 7 to unconnected-(U3-NC-Pad7).
Add net unconnected-(U3-NC-Pad7).
Connected U3 pin 16 to 3.3VD.
Connected U3 pin 4 to 3.3VD.
Connected U3 pin 15 to unconnected-(U3-R232-Pad15).
Add net unconnected-(U3-R232-Pad15).
Connected U6 pin 7 to Net-(U6-SW).
Updated Y1 unit metadata.
Connected Y1 pin 1 to /HSE_IN.
Connected Y1 pin 2 to /HSE_OUT.
Updated Y1 sheetfile to 'Energy_Meter.kicad_sch'.
Updated Y1 sheetname to '/'.
Updated Y1 fields.
Updated Y1 symbol association from  to /8b861d39-8fe3-4208-917b-d46f30b4d08a.
Changed Y1 value from Crystal_HC49-4H_Vertical to Crystal_8MHz.
Changed REF** reference designator to Y1.
Added Y1 (footprint 'Crystal:Crystal_HC49-4H_Vertical').
Updated U6 unit metadata.
Connected U3 pin 14 to unconnected-(U3-~{RTS}-Pad14).
Connected U6 pin 4 to Net-(D1-K).
Connected U6 pin 5 to Net-(U6-KEY).
Connected U6 pin 2 to Net-(D1-A).
Connected U6 pin 1 to /VBUS.
Connected U6 pin 9 to GND.
Connected U6 pin 8 to 5V.
Connected U6 pin 3 to Net-(D3-A).
Connected U6 pin 6 to /BAT.
Updated U6 sheetfile to 'Energy_Meter.kicad_sch'.
Updated U6 sheetname to '/'.
Updated U6 fields.
Connected U2 pin 9 to IN-.
Changed REF** reference designator to U3.
Added U3 (footprint 'Package_SO:SOIC-16_3.9x9.9mm_P1.27mm').
Updated U2 unit metadata.
Connected U2 pin 7 to GND.
Connected U2 pin 3 to Net-(U2-~{Alert}).
Connected U2 pin 2 to GND.
Connected U2 pin 8 to IN-.
Connected U2 pin 6 to 3.3VD.
Connected U2 pin 1 to GND.
Connected U2 pin 4 to /SDA1.
Connected U2 pin 10 to IN+.
Changed U3 value from SOIC-16_3.9x9.9mm_P1.27mm to CH340C.
Connected U2 pin 5 to /SCL1.
Updated U2 footprint filters to '*TSSOP*3x3mm?P0.5mm*'.
Updated U2 sheetfile to 'Energy_Meter.kicad_sch'.
Updated U2 sheetname to '/'.
Updated U2 fields.
Updated U2 symbol association from  to /f21c2c20-8940-4f55-b5f0-f423f46fdc72.
Changed U2 value from TSSOP-10_3x3mm_P0.5mm to INA238.
Changed REF** reference designator to U2.
Added U2 (footprint 'Package_SO:TSSOP-10_3x3mm_P0.5mm').
Updated U1 unit metadata.
Connected U1 pin 30 to /TX.
Connected U3 pin 11 to unconnected-(U3-~{RI}-Pad11).
Add net unconnected-(U3-~{RTS}-Pad14).
Connected U3 pin 1 to GND.
Connected U3 pin 13 to unconnected-(U3-~{DTR}-Pad13).
Add net unconnected-(U3-~{DTR}-Pad13).
Connected U3 pin 3 to /TX.
Connected U3 pin 2 to /RX.
Connected U3 pin 8 to unconnected-(U3-NC-Pad8).
Add net unconnected-(U3-NC-Pad8).
Connected U3 pin 5 to /USB_C+.
Connected U3 pin 9 to unconnected-(U3-~{CTS}-Pad9).
Add net unconnected-(U3-~{CTS}-Pad9).
Updated TP19 fields.
Add net unconnected-(U3-~{RI}-Pad11).
Connected U3 pin 10 to unconnected-(U3-~{DSR}-Pad10).
Add net unconnected-(U3-~{DSR}-Pad10).
Connected U3 pin 6 to /USB_C-.
Connected U3 pin 12 to unconnected-(U3-~{DCD}-Pad12).
Add net unconnected-(U3-~{DCD}-Pad12).
Updated U3 footprint filters to 'SOIC*3.9x9.9mm*P1.27mm*'.
Updated U3 sheetfile to 'Energy_Meter.kicad_sch'.
Updated U3 sheetname to '/'.
Updated U3 fields.
Updated U3 symbol association from  to /a818ab0d-8f18-48de-ae49-6ee34454573d.
Changed TP6 value from Val** to 0.5mm.
Updated TP7 symbol association from  to /55a78e85-db49-4651-8782-8550663e2d3d.
Changed TP7 value from Val** to 0.5mm.
Changed Ref** reference designator to TP7.
Added TP7 (footprint 'PCM_SparkFun-Connector:TestPoint-0.5mm').
Updated TP6 unit metadata.
Connected TP6 pin 1 to GND.
Updated TP6 footprint filters to 'Pin* Test*'.
Updated TP6 sheetfile to 'Energy_Meter.kicad_sch'.
Updated TP6 sheetname to '/'.
Updated TP6 fields.
Updated TP6 symbol association from  to /f7ee8c76-ff0c-42e0-bc54-ca6df524732b.
Updated TP7 fields.
Changed Ref** reference designator to TP6.
Added TP6 (footprint 'PCM_SparkFun-Connector:TestPoint-0.5mm').
Updated TP5 unit metadata.
Connected TP5 pin 1 to Net-(C8-Pad1).
Updated TP5 footprint filters to 'Pin* Test*'.
Updated TP5 sheetfile to 'Energy_Meter.kicad_sch'.
Updated TP5 sheetname to '/'.
Updated TP5 fields.
Updated TP5 symbol association from  to /9b9cc643-683e-44af-baca-6b984bb525c5.
Changed TP5 value from Val** to 0.5mm.
Changed Ref** reference designator to TP5.
Updated TP8 sheetfile to 'Energy_Meter.kicad_sch'.
Updated TP9 footprint filters to 'Pin* Test*'.
Updated TP9 sheetfile to 'Energy_Meter.kicad_sch'.
Updated TP9 sheetname to '/'.
Updated TP9 fields.
Updated TP9 symbol association from  to /6b77d2d3-3641-49c4-a046-67ad447594a6.
Changed TP9 value from Val** to 0.5mm.
Changed Ref** reference designator to TP9.
Added TP9 (footprint 'PCM_SparkFun-Connector:TestPoint-0.5mm').
Updated TP8 unit metadata.
Connected TP8 pin 1 to Net-(R14-Pad1).
Updated TP8 footprint filters to 'Pin* Test*'.
Added TP5 (footprint 'PCM_SparkFun-Connector:TestPoint-0.5mm').
Updated TP8 sheetname to '/'.
Updated TP8 fields.
Updated TP8 symbol association from  to /661f7ee6-b1b3-4310-b39b-aa26ec17b494.
Changed TP8 value from Val** to 0.5mm.
Changed Ref** reference designator to TP8.
Added TP8 (footprint 'PCM_SparkFun-Connector:TestPoint-0.5mm').
Updated TP7 unit metadata.
Connected TP7 pin 1 to Net-(R15_Shunt1-Pad2).
Updated TP7 footprint filters to 'Pin* Test*'.
Updated TP7 sheetfile to 'Energy_Meter.kicad_sch'.
Updated TP7 sheetname to '/'.
Updated TP1 fields.
Updated TP2 sheetname to '/'.
Updated TP2 fields.
Updated TP2 symbol association from  to /e2f025a5-778d-404c-b3a6-f643b70ebfd4.
Changed TP2 value from Val** to 0.5mm.
Changed Ref** reference designator to TP2.
Added TP2 (footprint 'PCM_SparkFun-Connector:TestPoint-0.5mm').
Updated TP1 unit metadata.
Connected TP1 pin 1 to ADC2.
Updated TP1 footprint filters to 'Pin* Test*'.
Updated TP1 sheetfile to 'Energy_Meter.kicad_sch'.
Updated TP1 sheetname to '/'.
Updated TP2 sheetfile to 'Energy_Meter.kicad_sch'.
Updated TP1 symbol association from  to /d1444b62-7913-49b8-a09c-80821ec29a46.
Changed TP1 value from Val** to 0.5mm.
Changed Ref** reference designator to TP1.
Added TP1 (footprint 'PCM_SparkFun-Connector:TestPoint-0.5mm').
Updated T1 unit metadata.
Connected T1 pin 1 to Net-(R16-Pad2).
Connected T1 pin 2 to Net-(R17-Pad2).
Connected T1 pin 3 to Net-(R24-Pad1).
Connected T1 pin 4 to Net-(C11-Pad1).
Updated T1 sheetfile to 'Energy_Meter.kicad_sch'.
Updated T1 sheetname to '/'.
Connected TP3 pin 1 to GND.
Updated TP4 unit metadata.
Connected TP4 pin 1 to ADC1.
Updated TP4 footprint filters to 'Pin* Test*'.
Updated TP4 sheetfile to 'Energy_Meter.kicad_sch'.
Updated TP4 sheetname to '/'.
Updated TP4 fields.
Updated TP4 symbol association from  to /45650551-fdd0-44ae-a3d6-2cbaee5497ab.
Changed TP4 value from Val** to 0.5mm.
Changed Ref** reference designator to TP4.
Added TP4 (footprint 'PCM_SparkFun-Connector:TestPoint-0.5mm').
Updated TP3 unit metadata.
Connected TP9 pin 1 to /SDA1.
Updated TP3 footprint filters to 'Pin* Test*'.
Updated TP3 sheetfile to 'Energy_Meter.kicad_sch'.
Updated TP3 sheetname to '/'.
Updated TP3 fields.
Updated TP3 symbol association from  to /f1f94119-a13d-4731-88ad-48124542f785.
Changed TP3 value from Val** to 0.5mm.
Changed Ref** reference designator to TP3.
Added TP3 (footprint 'PCM_SparkFun-Connector:TestPoint-0.5mm').
Updated TP2 unit metadata.
Connected TP2 pin 1 to Net-(C11-Pad1).
Updated TP2 footprint filters to 'Pin* Test*'.
Connected TP15 pin 1 to 3.3VA.
Updated TP16 unit metadata.
Connected TP16 pin 1 to 5V.
Updated TP16 footprint filters to 'Pin* Test*'.
Updated TP16 sheetfile to 'Energy_Meter.kicad_sch'.
Updated TP16 sheetname to '/'.
Updated TP16 fields.
Updated TP16 symbol association from  to /eef2fdd6-9364-4114-a990-bf4599936f6a.
Changed TP16 value from Val** to 0.5mm.
Changed Ref** reference designator to TP16.
Added TP16 (footprint 'PCM_SparkFun-Connector:TestPoint-0.5mm').
Updated TP15 unit metadata.
Added TP17 (footprint 'PCM_SparkFun-Connector:TestPoint-0.5mm').
Updated TP15 footprint filters to 'Pin* Test*'.
Updated TP15 sheetfile to 'Energy_Meter.kicad_sch'.
Updated TP15 sheetname to '/'.
Updated TP15 fields.
Updated TP15 symbol association from  to /60dcd4a4-90f6-4754-9e72-7a6e8b76b2ce.
Changed TP15 value from Val** to 0.5mm.
Changed Ref** reference designator to TP15.
Added TP15 (footprint 'PCM_SparkFun-Connector:TestPoint-0.5mm').
Updated TP14 unit metadata.
Connected TP14 pin 1 to 3.3VD.
Updated TP14 footprint filters to 'Pin* Test*'.
Changed TP18 value from Val** to 0.5mm.
Updated TP19 symbol association from  to /258e1478-4668-4c86-9635-98287a04e44f.
Changed TP19 value from Val** to 0.5mm.
Changed Ref** reference designator to TP19.
Added TP19 (footprint 'PCM_SparkFun-Connector:TestPoint-0.5mm').
Updated TP18 unit metadata.
Connected TP18 pin 1 to /BAT.
Updated TP18 footprint filters to 'Pin* Test*'.
Updated TP18 sheetfile to 'Energy_Meter.kicad_sch'.
Updated TP18 sheetname to '/'.
Updated TP18 fields.
Updated TP18 symbol association from  to /09df094c-8290-4de7-9c61-67f5fbcf7706.
Updated TP14 sheetfile to 'Energy_Meter.kicad_sch'.
Changed Ref** reference designator to TP18.
Added TP18 (footprint 'PCM_SparkFun-Connector:TestPoint-0.5mm').
Updated TP17 unit metadata.
Connected TP17 pin 1 to GND.
Updated TP17 footprint filters to 'Pin* Test*'.
Updated TP17 sheetfile to 'Energy_Meter.kicad_sch'.
Updated TP17 sheetname to '/'.
Updated TP17 fields.
Updated TP17 symbol association from  to /87fd4add-c5ad-4105-aab9-c23ca5a270ad.
Changed TP17 value from Val** to 0.5mm.
Changed Ref** reference designator to TP17.
Added TP11 (footprint 'PCM_SparkFun-Connector:TestPoint-0.5mm').
Changed Ref** reference designator to TP12.
Added TP12 (footprint 'PCM_SparkFun-Connector:TestPoint-0.5mm').
Updated TP11 unit metadata.
Connected TP11 pin 1 to 3.3VD.
Updated TP11 footprint filters to 'Pin* Test*'.
Updated TP11 sheetfile to 'Energy_Meter.kicad_sch'.
Updated TP11 sheetname to '/'.
Updated TP11 fields.
Updated TP11 symbol association from  to /f54d05ac-d193-42d7-8e33-60523b00556a.
Changed TP11 value from Val** to 0.5mm.
Changed Ref** reference designator to TP11.
Changed TP12 value from Val** to 0.5mm.
Updated TP10 unit metadata.
Connected TP10 pin 1 to /SCL1.
Updated TP10 footprint filters to 'Pin* Test*'.
Updated TP10 sheetfile to 'Energy_Meter.kicad_sch'.
Updated TP10 sheetname to '/'.
Updated TP10 fields.
Updated TP10 symbol association from  to /40bf22b9-3368-400b-bc74-7549c379b06c.
Changed TP10 value from Val** to 0.5mm.
Changed Ref** reference designator to TP10.
Added TP10 (footprint 'PCM_SparkFun-Connector:TestPoint-0.5mm').
Updated TP9 unit metadata.
Updated TP13 fields.
Updated TP14 sheetname to '/'.
Updated TP14 fields.
Updated TP14 symbol association from  to /4f326855-b9da-4d6b-8082-c055f80f8b03.
Changed TP14 value from Val** to 0.5mm.
Changed Ref** reference designator to TP14.
Added TP14 (footprint 'PCM_SparkFun-Connector:TestPoint-0.5mm').
Updated TP13 unit metadata.
Connected TP13 pin 1 to /VBUS.
Updated TP13 footprint filters to 'Pin* Test*'.
Updated TP13 sheetfile to 'Energy_Meter.kicad_sch'.
Updated TP13 sheetname to '/'.
Updated T1 fields.
Updated TP13 symbol association from  to /ccbf3232-c57a-43d1-bc3d-0d1f89b06483.
Changed TP13 value from Val** to 0.5mm.
Changed Ref** reference designator to TP13.
Added TP13 (footprint 'PCM_SparkFun-Connector:TestPoint-0.5mm').
Updated TP12 unit metadata.
Connected TP12 pin 1 to IN-.
Updated TP12 footprint filters to 'Pin* Test*'.
Updated TP12 sheetfile to 'Energy_Meter.kicad_sch'.
Updated TP12 sheetname to '/'.
Updated TP12 fields.
Updated TP12 symbol association from  to /5952231a-c603-4c76-a9a0-0e13560029ab.
Connected C22 pin 2 to GND.
Added C24 (footprint 'Capacitor_THT:CP_Radial_D5.0mm_P2.00mm').
Updated C23 unit metadata.
Connected C23 pin 1 to GND.
Connected C23 pin 2 to 3.3VA.
Updated C23 sheetfile to 'Energy_Meter.kicad_sch'.
Updated C23 sheetname to '/'.
Updated C23 fields.
Updated C23 symbol association from  to /15465e66-f655-465b-8e03-f7d215192fd5.
Changed C23 value from C_Disc_D5.0mm_W2.5mm_P2.50mm to 100nF_Ceramic.
Changed REF** reference designator to C23.
Added C23 (footprint 'Capacitor_THT:C_Disc_D5.0mm_W2.5mm_P2.50mm').
Updated C22 unit metadata.
Changed REF** reference designator to C24.
Connected C22 pin 1 to 3.3VD.
Updated C22 footprint filters to 'C_*'.
Updated C22 sheetfile to 'Energy_Meter.kicad_sch'.
Updated C22 sheetname to '/'.
Updated C22 fields.
Updated C22 symbol association from  to /fd998f8f-61a9-413d-a34b-5183592d7dd2.
Changed C22 value from C_0603_1608Metric to 1uF_0603_25V.
Changed REF** reference designator to C22.
Added C22 (footprint 'Capacitor_SMD:C_0603_1608Metric').
Updated C21 unit metadata.
Connected C21 pin 1 to GND.
Changed C25 value from C_Disc_D5.0mm_W2.5mm_P2.50mm to 100nF_Ceramic.
Updated C26 symbol association from  to /29a2a541-76a7-47e5-8784-b9ede7aa3d51.
Changed C26 value from C_Disc_D5.0mm_W2.5mm_P2.50mm to 100nF_Ceramic.
Changed REF** reference designator to C26.
Added C26 (footprint 'Capacitor_THT:C_Disc_D5.0mm_W2.5mm_P2.50mm').
Updated C25 unit metadata.
Connected C25 pin 1 to GND.
Connected C25 pin 2 to 5V.
Updated C25 sheetfile to 'Energy_Meter.kicad_sch'.
Updated C25 sheetname to '/'.
Updated C25 fields.
Updated C25 symbol association from  to /2e4b0b94-9174-43a2-8c6e-895998e1de18.
Connected C21 pin 2 to 3.3VA.
Changed REF** reference designator to C25.
Added C25 (footprint 'Capacitor_THT:C_Disc_D5.0mm_W2.5mm_P2.50mm').
Updated C24 unit metadata.
Connected C24 pin 2 to GND.
Connected C24 pin 1 to 5V.
Updated C24 footprint filters to 'Capacitor_THT:CP_Radial_D5.0mm_* Capacitor_THT:CP_Radial_D4.0mm_* Capacitor_THT:CP_Radial_D6.3mm_* Capacitor_THT:CP_Radial_D7.5mm_* Capacitor_THT:CP_Radial_D8.0mm_* Capacitor_THT:CP_Radial_D10.0mm_* Capacitor_THT:CP_Radial_D14.0mm_* Capacitor_THT:CP_Radial_D16.0mm_* Capacitor_THT:CP_Radial_D18.0mm_*'.
Updated C24 sheetfile to 'Energy_Meter.kicad_sch'.
Updated C24 sheetname to '/'.
Updated C24 fields.
Updated C24 symbol association from  to /2c59f82a-6267-468e-b971-d5179faa1ba3.
Changed C24 value from CP_Radial_D5.0mm_P2.00mm to 10uF_16V.
Updated C18 sheetfile to 'Energy_Meter.kicad_sch'.
Updated C19 sheetfile to 'Energy_Meter.kicad_sch'.
Updated C19 sheetname to '/'.
Updated C19 fields.
Updated C19 symbol association from  to /c7458abb-aa6b-42df-853d-fb25b074efbc.
Changed C19 value from C_0603_1608Metric to 100nF_0603_16V.
Changed REF** reference designator to C19.
Added C19 (footprint 'Capacitor_SMD:C_0603_1608Metric').
Updated C18 unit metadata.
Connected C18 pin 1 to 3.3VD.
Connected C18 pin 2 to GND.
Updated C18 footprint filters to 'C_*'.
Updated C19 footprint filters to 'C_*'.
Updated C18 sheetname to '/'.
Updated C18 fields.
Updated C18 symbol association from  to /2afd3478-f027-49a6-ad92-a3e880ca1bb3.
Changed C18 value from C_0603_1608Metric to 100nF_0603_16V.
Changed REF** reference designator to C18.
Added C18 (footprint 'Capacitor_SMD:C_0603_1608Metric').
Updated C17 unit metadata.
Connected C17 pin 2 to GND.
Connected C17 pin 1 to 3.3VD.
Updated C17 footprint filters to 'C_*'.
Updated C17 sheetfile to 'Energy_Meter.kicad_sch'.
Connected C20 pin 2 to GND.
Add net 3.3VA.
Updated C21 footprint filters to 'C_*'.
Updated C21 sheetfile to 'Energy_Meter.kicad_sch'.
Updated C21 sheetname to '/'.
Updated C21 fields.
Updated C21 symbol association from  to /3922e4b4-5db9-43dd-9567-e59f0d6a7122.
Changed C21 value from C_0603_1608Metric to 10nF_0603_25V.
Changed REF** reference designator to C21.
Added C21 (footprint 'Capacitor_SMD:C_0603_1608Metric').
Updated C20 unit metadata.
Connected C20 pin 1 to 3.3VD.
Updated C26 fields.
Updated C20 footprint filters to 'C_*'.
Updated C20 sheetfile to 'Energy_Meter.kicad_sch'.
Updated C20 sheetname to '/'.
Updated C20 fields.
Updated C20 symbol association from  to /1ab52a96-d202-46f8-bdbc-bca580df1a4e.
Changed C20 value from C_0603_1608Metric to 10nF_0603_25V.
Changed REF** reference designator to C20.
Added C20 (footprint 'Capacitor_SMD:C_0603_1608Metric').
Updated C19 unit metadata.
Connected C19 pin 1 to 3.3VD.
Connected C19 pin 2 to GND.
Added C33 (footprint 'Components_Footprint:CAPRB250W50L400T250H550').
Added C35 (footprint 'Components_Footprint:CAPRB250W50L400T250H550').
Updated C33 unit metadata.
Connected C33 pin 1 to /HSE_OUT.
Add net /HSE_OUT.
Connected C33 pin 2 to GND.
Updated C33 sheetfile to 'Energy_Meter.kicad_sch'.
Updated C33 sheetname to '/'.
Updated C33 fields.
Updated C33 symbol association from  to /5282df6e-b3da-4eee-b894-97895dd36dc3.
Changed C33 value from CAPRB250W50L400T250H550 to 22pF.
Changed REF** reference designator to C33.
Changed REF** reference designator to C35.
Updated C32 unit metadata.
Connected C32 pin 1 to GND.
Connected C32 pin 2 to 3.3VA.
Updated C32 sheetfile to 'Energy_Meter.kicad_sch'.
Updated C32 sheetname to '/'.
Updated C32 fields.
Updated C32 symbol association from  to /e8695f93-6a5b-4bac-85d1-9c51d3ab9c6c.
Changed C32 value from C_Disc_D5.0mm_W2.5mm_P2.50mm to 100nF_Ceramic.
Changed REF** reference designator to C32.
Added C32 (footprint 'Capacitor_THT:C_Disc_D5.0mm_W2.5mm_P2.50mm').
Updated C31 unit metadata.
Changed D1 value from LED_1206_3216Metric to Blue LED.
Added D2 (footprint 'LED_SMD:LED_1206_3216Metric').
Updated D1 unit metadata.
Connected D1 pin 2 to Net-(D1-A).
Add net Net-(D1-A).
Connected D1 pin 1 to Net-(D1-K).
Add net Net-(D1-K).
Updated D1 footprint filters to 'LED* LED_SMD:* LED_THT:*'.
Updated D1 sheetfile to 'Energy_Meter.kicad_sch'.
Updated D1 sheetname to '/'.
Updated D1 fields.
Updated D1 symbol association from  to /f0566963-24a0-4803-b19a-b51260247470.
Connected C31 pin 1 to GND.
Changed REF** reference designator to D1.
Added D1 (footprint 'LED_SMD:LED_1206_3216Metric').
Updated C35 unit metadata.
Connected C35 pin 1 to /HSE_IN.
Add net /HSE_IN.
Connected C35 pin 2 to GND.
Updated C35 sheetfile to 'Energy_Meter.kicad_sch'.
Updated C35 sheetname to '/'.
Updated C35 fields.
Updated C35 symbol association from  to /ef7a245e-a575-49bb-878a-e933d29d4a9a.
Changed C35 value from CAPRB250W50L400T250H550 to 22pF.
Updated C28 sheetfile to 'Energy_Meter.kicad_sch'.
Updated C29 sheetfile to 'Energy_Meter.kicad_sch'.
Updated C29 sheetname to '/'.
Updated C29 fields.
Updated C29 symbol association from  to /321a9ee2-1c29-4aa7-8f25-ae607ea0952d.
Changed C29 value from C_Disc_D5.0mm_W2.5mm_P2.50mm to 100nF_Ceramic.
Changed REF** reference designator to C29.
Added C29 (footprint 'Capacitor_THT:C_Disc_D5.0mm_W2.5mm_P2.50mm').
Updated C28 unit metadata.
Connected C28 pin 1 to GND.
Connected C28 pin 2 to Net-(C28-Pad2).
Add net Net-(C28-Pad2).
Connected C29 pin 1 to GND.
Updated C28 sheetname to '/'.
Updated C28 fields.
Updated C28 symbol association from  to /c2912e25-3963-4a20-97da-b8efa3f3bcac.
Changed C28 value from C_Disc_D5.0mm_W2.5mm_P2.50mm to 100nF_Ceramic.
Changed REF** reference designator to C28.
Added C28 (footprint 'Capacitor_THT:C_Disc_D5.0mm_W2.5mm_P2.50mm').
Updated C26 unit metadata.
Connected C26 pin 1 to GND.
Connected C26 pin 2 to 3.3VD.
Updated C26 sheetfile to 'Energy_Meter.kicad_sch'.
Updated C26 sheetname to '/'.
Add net Net-(C30-Pad2).
Connected C31 pin 2 to Net-(C31-Pad2).
Add net Net-(C31-Pad2).
Updated C31 sheetfile to 'Energy_Meter.kicad_sch'.
Updated C31 sheetname to '/'.
Updated C31 fields.
Updated C31 symbol association from  to /ab570e18-397b-4b50-af91-c94113e9683e.
Changed C31 value from C_Disc_D5.0mm_W2.5mm_P2.50mm to 100nF_Ceramic.
Changed REF** reference designator to C31.
Added C31 (footprint 'Capacitor_THT:C_Disc_D5.0mm_W2.5mm_P2.50mm').
Updated C30 unit metadata.
Connected C30 pin 2 to Net-(C30-Pad2).
Updated C17 sheetname to '/'.
Connected C30 pin 1 to GND.
Updated C30 sheetfile to 'Energy_Meter.kicad_sch'.
Updated C30 sheetname to '/'.
Updated C30 fields.
Updated C30 symbol association from  to /92302782-0415-4b08-9566-0049cfad93c1.
Changed C30 value from C_Disc_D5.0mm_W2.5mm_P2.50mm to 100nF_Ceramic.
Changed REF** reference designator to C30.
Added C30 (footprint 'Capacitor_THT:C_Disc_D5.0mm_W2.5mm_P2.50mm').
Updated C29 unit metadata.
Connected C29 pin 2 to Net-(C29-Pad2).
Add net Net-(C29-Pad2).
Updated C5 unit metadata.
Updated C6 unit metadata.
Connected C6 pin 1 to 5V.
Connected C6 pin 2 to GND.
Updated C6 footprint filters to 'C_*'.
Updated C6 sheetfile to 'Energy_Meter.kicad_sch'.
Updated C6 sheetname to '/'.
Updated C6 fields.
Updated C6 symbol association from  to /c19f114c-e6e0-4894-bb6b-7d2d292f3190.
Changed C6 value from C_1206_3216Metric to 22 uF.
Changed REF** reference designator to C6.
Added C6 (footprint 'Capacitor_SMD:C_1206_3216Metric').
Added C7 (footprint 'Capacitor_SMD:C_1206_3216Metric').
Connected C5 pin 1 to Net-(C5-Pad1).
Add net Net-(C5-Pad1).
Connected C5 pin 2 to GND.
Updated C5 footprint filters to 'C_*'.
Updated C5 sheetfile to 'Energy_Meter.kicad_sch'.
Updated C5 sheetname to '/'.
Updated C5 fields.
Updated C5 symbol association from  to /dc0af118-5e79-4941-8920-6deb85d35f85.
Changed C5 value from C_1210_3225Metric to 10uF.
Changed REF** reference designator to C5.
Added C5 (footprint 'PCM_SparkFun-Capacitor:C_1210_3225Metric').
Changed REF** reference designator to C8.
Added C9 (footprint 'Capacitor_THT:CP_Radial_D5.0mm_P2.00mm').
Updated C8 unit metadata.
Connected C8 pin 1 to Net-(C8-Pad1).
Add net Net-(C8-Pad1).
Connected C8 pin 2 to GND.
Updated C8 footprint filters to 'Capacitor_THT:CP_Radial_D5.0mm_* Capacitor_THT:CP_Radial_D4.0mm_* Capacitor_THT:CP_Radial_D6.3mm_* Capacitor_THT:CP_Radial_D7.5mm_* Capacitor_THT:CP_Radial_D8.0mm_* Capacitor_THT:CP_Radial_D10.0mm_* Capacitor_THT:CP_Radial_D14.0mm_* Capacitor_THT:CP_Radial_D16.0mm_* Capacitor_THT:CP_Radial_D18.0mm_*'.
Updated C8 sheetfile to 'Energy_Meter.kicad_sch'.
Updated C8 sheetname to '/'.
Updated C8 fields.
Updated C8 symbol association from  to /4f53ff08-fc1d-48af-b51b-cfc3ed2f12bc.
Changed C8 value from CP_Radial_D5.0mm_P2.00mm to 10uF_16V.
Updated C4 unit metadata.
Added C8 (footprint 'Capacitor_THT:CP_Radial_D5.0mm_P2.00mm').
Updated C7 unit metadata.
Connected C7 pin 2 to GND.
Connected C7 pin 1 to 5V.
Updated C7 footprint filters to 'C_*'.
Updated C7 sheetfile to 'Energy_Meter.kicad_sch'.
Updated C7 sheetname to '/'.
Updated C7 fields.
Updated C7 symbol association from  to /a62435fa-a2c3-4ceb-b064-31b9c3b8c45a.
Changed C7 value from C_1206_3216Metric to 22 uF.
Changed REF** reference designator to C7.
Updated C1 unit metadata.
Connected C2 pin 1 to /VBUS.
Add net /VBUS.
Connected C2 pin 2 to GND.
Updated C2 footprint filters to 'C_*'.
Updated C2 sheetfile to 'Energy_Meter.kicad_sch'.
Updated C2 sheetname to '/'.
Updated C2 fields.
Updated C2 symbol association from  to /9c145543-e300-4436-b8e6-12f65d53e1a7.
Changed C2 value from C_1206_3216Metric to 10 uF.
Changed REF** reference designator to C2.
Added C2 (footprint 'Capacitor_SMD:C_1206_3216Metric').
Updated C2 unit metadata.
Connected C1 pin 2 to GND.
Add net GND.
Connected C1 pin 1 to Net-(C1-Pad1).
Add net Net-(C1-Pad1).
Updated C1 footprint filters to 'C_*'.
Updated C1 sheetfile to 'Energy_Meter.kicad_sch'.
Updated C1 sheetname to '/'.
Updated C1 fields.
Updated C1 symbol association from  to /4c4ca0da-4f94-4fe0-9759-c5f0013ad180.
Changed C1 value from C_1206_3216Metric to 10 uF.
Changed REF** reference designator to C1.
Updated C3 unit metadata.
Connected C4 pin 1 to 5V.
Add net 5V.
Connected C4 pin 2 to GND.
Updated C4 footprint filters to 'C_*'.
Updated C4 sheetfile to 'Energy_Meter.kicad_sch'.
Updated C4 sheetname to '/'.
Updated C4 fields.
Updated C4 symbol association from  to /46750d15-e548-4dbb-80b6-7b489f7f53b5.
Changed C4 value from C_1206_3216Metric to 22 uF.
Changed REF** reference designator to C4.
Added C4 (footprint 'Capacitor_SMD:C_1206_3216Metric').
Changed REF** reference designator to C9.
Connected C3 pin 1 to /BAT.
Add net /BAT.
Connected C3 pin 2 to GND.
Updated C3 footprint filters to 'C_*'.
Updated C3 sheetfile to 'Energy_Meter.kicad_sch'.
Updated C3 sheetname to '/'.
Updated C3 fields.
Updated C3 symbol association from  to /e6b51028-2adf-4468-95eb-2f63435be06b.
Changed C3 value from C_1206_3216Metric to 10 uF.
Changed REF** reference designator to C3.
Added C3 (footprint 'Capacitor_SMD:C_1206_3216Metric').
Updated C14 sheetname to '/'.
Updated C15 symbol association from  to /75ddc3e3-4df2-40ec-b71c-87b901fafc08.
Changed C15 value from C_0603_1608Metric to 100nF_0603_16V.
Changed REF** reference designator to C15.
Added C15 (footprint 'Capacitor_SMD:C_0603_1608Metric').
Updated C14 unit metadata.
Connected C14 pin 1 to IN+.
Add net IN+.
Connected C14 pin 2 to IN-.
Add net IN-.
Updated C14 footprint filters to 'C_*'.
Updated C14 sheetfile to 'Energy_Meter.kicad_sch'.
Updated C15 fields.
Updated C14 fields.
Updated C14 symbol association from  to /e60c779c-7d28-46e2-88ee-557ea930da91.
Changed C14 value from C_0603_1608Metric to 0.1uF.
Changed REF** reference designator to C14.
Added C14 (footprint 'PCM_SparkFun-Capacitor:C_0603_1608Metric').
Updated C13 unit metadata.
Connected C13 pin 2 to GND.
Connected C13 pin 1 to 3.3VD.
Updated C13 footprint filters to 'C_*'.
Updated C13 sheetfile to 'Energy_Meter.kicad_sch'.
Updated C13 sheetname to '/'.
Updated C16 fields.
Updated C17 fields.
Updated C17 symbol association from  to /6c82aa47-69d9-4db6-97c0-2bd5995b6cea.
Changed C17 value from C_0603_1608Metric to 100nF_0603_16V.
Changed REF** reference designator to C17.
Added C17 (footprint 'Capacitor_SMD:C_0603_1608Metric').
Updated C16 unit metadata.
Connected C16 pin 1 to 3.3VD.
Connected C16 pin 2 to GND.
Updated C16 footprint filters to 'C_*'.
Updated C16 sheetfile to 'Energy_Meter.kicad_sch'.
Updated C16 sheetname to '/'.
Updated C13 fields.
Updated C16 symbol association from  to /84366609-2ca2-4785-916e-59cc60f39337.
Changed C16 value from C_0603_1608Metric to 100nF_0603_16V.
Changed REF** reference designator to C16.
Added C16 (footprint 'Capacitor_SMD:C_0603_1608Metric').
Updated C15 unit metadata.
Connected C15 pin 1 to /TFT_RST.
Add net /TFT_RST.
Connected C15 pin 2 to GND.
Updated C15 footprint filters to 'C_*'.
Updated C15 sheetfile to 'Energy_Meter.kicad_sch'.
Updated C15 sheetname to '/'.
Changed REF** reference designator to C10.
Changed C11 value from CP_Radial_D5.0mm_P2.00mm to 10uF_16V.
Changed REF** reference designator to C11.
Added C11 (footprint 'Capacitor_THT:CP_Radial_D5.0mm_P2.00mm').
Updated C10 unit metadata.
Connected C10 pin 2 to 3.3VD.
Connected C10 pin 1 to GND.
Updated C10 sheetfile to 'Energy_Meter.kicad_sch'.
Updated C10 sheetname to '/'.
Updated C10 fields.
Updated C10 symbol association from  to /1f272da7-28ad-41d6-943f-bf37fd46d00d.
Changed C10 value from C_Disc_D5.0mm_W2.5mm_P2.50mm to 100nF_Ceramic.
Updated C11 symbol association from  to /12ae69e4-3bd2-4fa9-92e7-8c2d2d82d77f.
Added C10 (footprint 'Capacitor_THT:C_Disc_D5.0mm_W2.5mm_P2.50mm').
Updated C9 unit metadata.
Connected C9 pin 1 to 3.3VD.
Add net 3.3VD.
Connected C9 pin 2 to GND.
Updated C9 footprint filters to 'Capacitor_THT:CP_Radial_D5.0mm_* Capacitor_THT:CP_Radial_D4.0mm_* Capacitor_THT:CP_Radial_D6.3mm_* Capacitor_THT:CP_Radial_D7.5mm_* Capacitor_THT:CP_Radial_D8.0mm_* Capacitor_THT:CP_Radial_D10.0mm_* Capacitor_THT:CP_Radial_D14.0mm_* Capacitor_THT:CP_Radial_D16.0mm_* Capacitor_THT:CP_Radial_D18.0mm_*'.
Updated C9 sheetfile to 'Energy_Meter.kicad_sch'.
Updated C9 sheetname to '/'.
Updated C9 fields.
Updated C9 symbol association from  to /df9c76cf-6f45-4415-9db8-4bf14a5982ac.
Changed C9 value from CP_Radial_D5.0mm_P2.00mm to 10uF_16V.
Updated C12 symbol association from  to /0741aaf9-4093-4321-93f8-180a72351281.
Updated C13 symbol association from  to /73960ead-f6f1-440d-a05d-c83e0f7719a5.
Changed C13 value from C_0603_1608Metric to 1uF_0603_25V.
Changed REF** reference designator to C13.
Added C13 (footprint 'Capacitor_SMD:C_0603_1608Metric').
Updated C12 unit metadata.
Connected C12 pin 1 to 3.3VD.
Connected C12 pin 2 to GND.
Updated C12 footprint filters to 'C_*'.
Updated C12 sheetfile to 'Energy_Meter.kicad_sch'.
Updated C12 sheetname to '/'.
Updated C12 fields.
Updated R11 sheetname to '/'.
Changed C12 value from ? to 0.1uF_0603_16V.
Changed C? reference designator to C12.
Added C12 (footprint 'PCM_4ms_Capacitor:C_0603').
Updated C11 unit metadata.
Connected C11 pin 1 to Net-(C11-Pad1).
Add net Net-(C11-Pad1).
Connected C11 pin 2 to GND.
Updated C11 footprint filters to 'Capacitor_THT:CP_Radial_D5.0mm_* Capacitor_THT:CP_Radial_D4.0mm_* Capacitor_THT:CP_Radial_D6.3mm_* Capacitor_THT:CP_Radial_D7.5mm_* Capacitor_THT:CP_Radial_D8.0mm_* Capacitor_THT:CP_Radial_D10.0mm_* Capacitor_THT:CP_Radial_D14.0mm_* Capacitor_THT:CP_Radial_D16.0mm_* Capacitor_THT:CP_Radial_D18.0mm_*'.
Updated C11 sheetfile to 'Energy_Meter.kicad_sch'.
Updated C11 sheetname to '/'.
Updated C11 fields.
Changed REF** reference designator to R2.
Changed REF** reference designator to R3.
Added R3 (footprint 'Resistor_SMD:R_1206_3216Metric').
Updated R2 unit metadata.
Connected R2 pin 2 to Net-(J3-CC1).
Connected R2 pin 1 to GND.
Updated R2 footprint filters to 'R_*'.
Updated R2 sheetfile to 'Energy_Meter.kicad_sch'.
Updated R2 sheetname to '/'.
Updated R2 fields.
Updated R2 symbol association from  to /dc6c44bd-eaa2-43b5-ab80-1ac492e876e2.
Changed R2 value from R_1206_3216Metric to 5.1K.
Changed R3 value from R_1206_3216Metric to 2Ω.
Added R2 (footprint 'Resistor_SMD:R_1206_3216Metric').
Updated R1 unit metadata.
Connected R1 pin 1 to GND.
Connected R1 pin 2 to Net-(J3-CC2).
Updated R1 footprint filters to 'R_*'.
Updated R1 sheetfile to 'Energy_Meter.kicad_sch'.
Updated R1 sheetname to '/'.
Updated R1 fields.
Updated R1 symbol association from  to /8be05807-b398-4c60-a9da-1d78f36c5e56.
Changed R1 value from R_1206_3216Metric to 5.1K.
Changed REF** reference designator to R1.
Changed R4 value from R_0603_1608Metric to 100.
Changed REF** reference designator to R4_Burden1.
Added R4_Burden1 (footprint 'Components_Footprint:RESC3116X65N').
Updated R4 unit metadata.
Connected R4 pin 1 to /EC_A.
Add net /EC_A.
Connected R4 pin 2 to Net-(C29-Pad2).
Updated R4 footprint filters to 'R_*'.
Updated R4 sheetfile to 'Energy_Meter.kicad_sch'.
Updated R4 sheetname to '/'.
Updated R4 fields.
Updated R4 symbol association from  to /8371d5e1-ec2c-49e3-be3e-1a75001ea86a.
Added R1 (footprint 'Resistor_SMD:R_1206_3216Metric').
Changed REF** reference designator to R4.
Added R4 (footprint 'PCM_SparkFun-Resistor:R_0603_1608Metric').
Updated R3 unit metadata.
Connected R3 pin 2 to Net-(C1-Pad1).
Connected R3 pin 1 to /VBUS.
Updated R3 footprint filters to 'R_*'.
Updated R3 sheetfile to 'Energy_Meter.kicad_sch'.
Updated R3 sheetname to '/'.
Updated R3 fields.
Updated R3 symbol association from  to /334df98c-6f9e-4335-8122-47fd2e279080.
Connected J7 pin 1 to IN+.
Updated J8 unit metadata.
Connected J8 pin 1 to IN-.
Updated J8 footprint filters to 'Connector*:*_1x??-1SH*'.
Updated J8 sheetfile to 'Energy_Meter.kicad_sch'.
Updated J8 sheetname to '/'.
Updated J8 fields.
Updated J8 symbol association from  to /70b5dbf1-c73e-4ddd-a099-d09b9ba34176.
Changed J8 value from POMONA_73096-2 to Conn_01x01_Shielded.
Changed REF** reference designator to J8.
Added J8 (footprint 'Components_Footprint:POMONA_73096-2').
Updated J7 unit metadata.
Added J9 (footprint 'PCM_SparkFun-Connector:ScrewTerminal_1x02_P3.5mm_Horizontal_Black').
Updated J7 footprint filters to 'Connector*:*_1x??-1SH*'.
Updated J7 sheetfile to 'Energy_Meter.kicad_sch'.
Updated J7 sheetname to '/'.
Updated J7 fields.
Updated J7 symbol association from  to /cf8ee4c5-430d-492c-81a7-2ca75d5b22b2.
Changed J7 value from POMONA_73096-2 to Conn_01x01_Shielded.
Changed REF** reference designator to J7.
Added J7 (footprint 'Components_Footprint:POMONA_73096-2').
Updated J6 unit metadata.
Connected J6 pin 1 to AC_N.
Add net AC_N.
Added L1 (footprint 'Inductor_SMD:L_Sunlord_SWPA6028S').
Updated L1 unit metadata.
Connected L1 pin 2 to /BAT.
Connected L1 pin 1 to Net-(U6-SW).
Add net Net-(U6-SW).
Updated L1 footprint filters to 'Choke_* *Coil* Inductor_* L_*'.
Updated L1 sheetfile to 'Energy_Meter.kicad_sch'.
Updated L1 sheetname to '/'.
Updated L1 fields.
Updated L1 symbol association from  to /fcd8d108-72a2-42e1-b3b8-63f80d03cc31.
Changed L1 value from L_Sunlord_SWPA6028S to 1 µH.
Changed REF** reference designator to L1.
Changed R4_Burden1 value from RESC3116X65N to 360_1206.
Updated J9 unit metadata.
Connected J9 pin 1 to /BAT.
Connected J9 pin 2 to GND.
Updated J9 footprint filters to 'TerminalBlock*:*'.
Updated J9 sheetfile to 'Energy_Meter.kicad_sch'.
Updated J9 sheetname to '/'.
Updated J9 fields.
Updated J9 symbol association from  to /7f9534b1-fdfe-4363-af77-16b92368435f.
Changed J9 value from Screw_Terminal_3.5mm-2 to 3.5mm.
Changed REF** reference designator to J9.
Updated R9 fields.
Updated R10 fields.
Updated R10 symbol association from  to /b1447d86-92c2-4260-a437-864d22c5b76b.
Changed R10 value from R_0603_1608Metric to 100.
Changed REF** reference designator to R10.
Added R10 (footprint 'PCM_SparkFun-Resistor:R_0603_1608Metric').
Updated R9 unit metadata.
Connected R9 pin 1 to Net-(J1-Pad2).
Connected R9 pin 2 to ADC1.
Updated R9 footprint filters to 'Resistor_THT:R_Axial_DIN0207_L6.3mm_D2.5mm*'.
Updated R9 sheetfile to 'Energy_Meter.kicad_sch'.
Updated R9 sheetname to '/'.
Updated R10 sheetname to '/'.
Updated R9 symbol association from  to /15f41a29-5e98-44ef-9433-e3d40d2208ef.
Changed R9 value from R_Axial_DIN0207_L6.3mm_D2.5mm_P10.16mm_Horizontal to 1k.
Changed REF** reference designator to R9.
Added R9 (footprint 'Resistor_THT:R_Axial_DIN0207_L6.3mm_D2.5mm_P10.16mm_Horizontal').
Updated R8 unit metadata.
Connected R8 pin 2 to Net-(C8-Pad1).
Connected R8 pin 1 to GND.
Updated R8 footprint filters to 'Resistor_THT:R_Axial_DIN0207_L6.3mm_D2.5mm*'.
Updated R8 sheetfile to 'Energy_Meter.kicad_sch'.
Updated R8 sheetname to '/'.
Updated R8 fields.
Updated R10_Burden1 fields.
Updated R11 sheetfile to 'Energy_Meter.kicad_sch'.
Updated R11 fields.
Updated R11 symbol association from  to /bd4544c7-d112-4162-8cd3-d54f6bccbccf.
Changed R11 value from R_0603_1608Metric to 4.7k.
Changed REF** reference designator to R11.
Added R11 (footprint 'PCM_SparkFun-Resistor:R_0603_1608Metric').
Updated R10_Burden1 unit metadata.
Connected R10_Burden1 pin 1 to Net-(J1-Pad2).
Connected R10_Burden1 pin 2 to Net-(C8-Pad1).
Updated R10_Burden1 sheetfile to 'Energy_Meter.kicad_sch'.
Updated R10_Burden1 sheetname to '/'.
Updated R8 symbol association from  to /fcb8d141-203f-4849-b9f4-01b935f1f2c6.
Updated R10_Burden1 symbol association from  to /5e2c714b-e924-4a1d-ac3d-f57131b28496.
Changed R10_Burden1 value from RESC2012X60N to 33_0805.
Changed REF** reference designator to R10_Burden1.
Added R10_Burden1 (footprint 'Components_Footprint:RESC2012X60N').
Updated R10 unit metadata.
Connected R10 pin 1 to /EC_B.
Add net /EC_B.
Connected R10 pin 2 to Net-(C28-Pad2).
Updated R10 footprint filters to 'R_*'.
Updated R10 sheetfile to 'Energy_Meter.kicad_sch'.
Changed R5 value from R_1206_3216Metric to 10.
Changed REF** reference designator to R6.
Added R6 (footprint 'PCM_fab:R_1206').
Updated R5 unit metadata.
Connected R5 pin 1 to Net-(R15_Shunt1-Pad2).
Add net Net-(R15_Shunt1-Pad2).
Connected R5 pin 2 to IN+.
Updated R5 footprint filters to 'R_*'.
Updated R5 sheetfile to 'Energy_Meter.kicad_sch'.
Updated R5 sheetname to '/'.
Updated R5 fields.
Updated R5 symbol association from  to /0ec0309c-de2c-4379-af55-8263fb2b738b.
Changed R6 value from R_1206 to 2.
Changed REF** reference designator to R5.
Added R5 (footprint 'PCM_SparkFun-Resistor:R_1206_3216Metric').
Updated R4_Burden1 unit metadata.
Connected R4_Burden1 pin 2 to Net-(R24-Pad1).
Add net Net-(R24-Pad1).
Connected R4_Burden1 pin 1 to Net-(C11-Pad1).
Updated R4_Burden1 sheetfile to 'Energy_Meter.kicad_sch'.
Updated R4_Burden1 sheetname to '/'.
Updated R4_Burden1 fields.
Updated R4_Burden1 symbol association from  to /eaecf3db-bf12-4be7-b4ee-4fd229863209.
Changed R7 value from R_Axial_DIN0207_L6.3mm_D2.5mm_P10.16mm_Horizontal to 470k.
Changed R8 value from R_Axial_DIN0207_L6.3mm_D2.5mm_P10.16mm_Horizontal to 470k.
Changed REF** reference designator to R8.
Added R8 (footprint 'Resistor_THT:R_Axial_DIN0207_L6.3mm_D2.5mm_P10.16mm_Horizontal').
Updated R7 unit metadata.
Connected R7 pin 1 to Net-(C8-Pad1).
Connected R7 pin 2 to 3.3VA.
Updated R7 footprint filters to 'Resistor_THT:R_Axial_DIN0207_L6.3mm_D2.5mm*'.
Updated R7 sheetfile to 'Energy_Meter.kicad_sch'.
Updated R7 sheetname to '/'.
Updated R7 fields.
Updated R7 symbol association from  to /5da0f5df-1df9-4518-bd01-f0db46834804.
Changed D2 value from LED_1206_3216Metric to Blue LED.
Changed REF** reference designator to R7.
Added R7 (footprint 'Resistor_THT:R_Axial_DIN0207_L6.3mm_D2.5mm_P10.16mm_Horizontal').
Updated R6 unit metadata.
Connected R6 pin 2 to Net-(C5-Pad1).
Connected R6 pin 1 to /BAT.
Updated R6 footprint filters to '*R*1206*'.
Updated R6 sheetfile to 'Energy_Meter.kicad_sch'.
Updated R6 sheetname to '/'.
Updated R6 fields.
Updated R6 symbol association from  to /20a7df84-b91c-4e61-ab35-b067d17789bc.
Add net /TFT_BLK.
Connected DS1 pin 10 to unconnected-(DS1-SDCS-Pad10).
Add net unconnected-(DS1-SDCS-Pad10).
Updated D3 sheetfile to 'Energy_Meter.kicad_sch'.
Connected DS1 pin 3 to GND.
Connected DS1 pin 5 to /TFT_MISO.
Add net /TFT_MISO.
Connected DS1 pin 2 to unconnected-(DS1-3VO-Pad2).
Add net unconnected-(DS1-3VO-Pad2).
Connected DS1 pin 7 to /TFT_CS.
Add net /TFT_CS.
Connected DS1 pin 11 to /TFT_BLK.
Updated DS1 unit metadata.
Connected DS1 pin 1 to 3.3VD.
Connected DS1 pin 6 to /TFT_MOSI.
Add net /TFT_MOSI.
Connected DS1 pin 8 to /TFT_RST.
Connected DS1 pin 9 to /TFT_DC.
Add net /TFT_DC.
Connected DS1 pin 4 to /TFT_SCK.
Add net /TFT_SCK.
Updated D3 footprint filters to 'LED* LED_SMD:* LED_THT:*'.
Updated DS1 sheetfile to 'Energy_Meter.kicad_sch'.
Updated FB1 unit metadata.
Connected J1 pin 2 to Net-(J1-Pad2).
Add net Net-(J1-Pad2).
Updated J1 footprint filters to '*CUI?SJ?3523?SMT?TR*'.
Updated J1 sheetfile to 'Energy_Meter.kicad_sch'.
Updated J1 sheetname to '/'.
Updated J1 fields.
Updated J1 symbol association from  to /b2e00ff7-003a-487e-940a-d7fe980c2564.
Changed J1 value from Conn_Jack_Stereo_3.5mm_CUI_SJ-3523-SMT-TR to Conn_Jack_Stereo_3.5mm_SMD_RA.
Changed REF** reference designator to J1.
Added J1 (footprint 'PCM_fab:Conn_Jack_Stereo_3.5mm_CUI_SJ-3523-SMT-TR').
Updated DS1 sheetname to '/'.
Connected FB1 pin 1 to 3.3VA.
Connected FB1 pin 2 to 3.3VD.
Updated FB1 footprint filters to 'Inductor_* L_* *Ferrite*'.
Updated FB1 sheetfile to 'Energy_Meter.kicad_sch'.
Updated FB1 sheetname to '/'.
Updated FB1 fields.
Updated FB1 symbol association from  to /9db36ca0-83f1-4229-a7c4-a9959b71ec74.
Changed FB1 value from Ferrite_0805_2012Metric to FerriteBead.
Changed REF** reference designator to FB1.
Added FB1 (footprint 'PCM_Ferrite_SMD_AKL:Ferrite_0805_2012Metric').
Connected D4 pin 1 to Net-(D3-A).
Connected D6 pin 2 to GND.
Updated D6 footprint filters to 'TO-???* *_Diode_* *SingleDiode* D_*'.
Updated D6 sheetfile to 'Energy_Meter.kicad_sch'.
Updated D6 sheetname to '/'.
Updated D6 fields.
Updated D6 symbol association from  to /f92d3f83-5c8d-4587-9d5c-0e3fc6d8d62b.
Changed D6 value from D_SOD-523 to ESD5Z3V3.
Changed REF** reference designator to D6.
Added D6 (footprint 'PCM_Diode_SMD_AKL:D_SOD-523').
Updated D4 unit metadata.
Connected D4 pin 2 to Net-(D1-K).
Add net ADC1.
Updated D4 footprint filters to 'LED* LED_SMD:* LED_THT:*'.
Updated D4 sheetfile to 'Energy_Meter.kicad_sch'.
Updated D4 sheetname to '/'.
Updated D4 fields.
Updated D4 symbol association from  to /0d1dff0e-f1d7-40da-b704-63afc04dd932.
Changed D4 value from LED_1206_3216Metric to Blue LED.
Changed REF** reference designator to D4.
Added D4 (footprint 'LED_SMD:LED_1206_3216Metric').
Updated D3 unit metadata.
Connected D3 pin 2 to Net-(D3-A).
Updated D7 sheetfile to 'Energy_Meter.kicad_sch'.
Updated DS1 fields.
Updated DS1 symbol association from  to /1132e648-2121-4ea4-964b-20dc4785841e.
Changed DS1 value from MODULE_4311 to 4311.
Changed REF** reference designator to DS1.
Added DS1 (footprint 'Components_Footprint:MODULE_4311').
Updated D7 unit metadata.
Connected D7 pin 1 to ADC2.
Add net ADC2.
Connected D7 pin 2 to GND.
Updated D7 footprint filters to 'TO-???* *_Diode_* *SingleDiode* D_*'.
Add net unconnected-(J1-Pad3).
Updated D7 sheetname to '/'.
Updated D7 fields.
Updated D7 symbol association from  to /5bce2f66-3f52-419e-b147-337d9c49d3e1.
Connected D3 pin 1 to Net-(D1-K).
Changed D7 value from D_SOD-523 to ESD5Z3V3.
Add net Net-(D3-A).
Changed REF** reference designator to D7.
Added D7 (footprint 'PCM_Diode_SMD_AKL:D_SOD-523').
Updated D6 unit metadata.
Connected D6 pin 1 to ADC1.
Added J5 (footprint 'Components_Footprint:POMONA_73096-2').
Updated J5 footprint filters to 'Connector*:*_1x??-1SH*'.
Updated J5 sheetfile to 'Energy_Meter.kicad_sch'.
Updated J5 sheetname to '/'.
Updated J5 fields.
Updated J5 symbol association from  to /72d27712-ce66-4d34-9d0d-5de89d4f95aa.
Changed J5 value from POMONA_73096-2 to Conn_01x01_Shielded.
Changed D3 value from LED_1206_3216Metric to Blue LED.
Updated D3 symbol association from  to /2a45ce26-1b18-4c6a-91bc-e306b4f0d228.
Changed REF** reference designator to J5.
Updated D3 fields.
Updated D3 sheetname to '/'.
Add net AC_L.
Updated J3 unit metadata.
Connected J3 pin VBUS to /VBUS.
Connected J3 pin A5 to Net-(J3-CC1).
Add net Net-(J3-CC1).
Connected J3 pin VBUS to /VBUS.
Connected J3 pin S to GND.
Connected J3 pin NC2 to unconnected-(J3-NC-PadNC2).
Add net unconnected-(J3-NC-PadNC2).
Connected J3 pin GND to GND.
Connected J3 pin B8 to unconnected-(J3-NC-PadB8).
Added J6 (footprint 'Components_Footprint:POMONA_73096-2').
Changed REF** reference designator to D2.
Updated D2 symbol association from  to /726f907e-80c6-43a1-adb4-94b830b05096.
Updated J6 footprint filters to 'Connector*:*_1x??-1SH*'.
Updated J6 sheetfile to 'Energy_Meter.kicad_sch'.
Updated D2 fields.
Updated J6 sheetname to '/'.
Updated J6 fields.
Updated J6 symbol association from  to /9a73f045-67a3-4c15-b3a9-6a1395e411d7.
Changed J6 value from POMONA_73096-2 to Conn_01x01_Shielded.
Changed REF** reference designator to J6.
Add net unconnected-(J3-NC-PadB8).
Updated J5 unit metadata.
Updated D2 sheetname to '/'.
Updated D2 sheetfile to 'Energy_Meter.kicad_sch'.
Updated D2 footprint filters to 'LED* LED_SMD:* LED_THT:*'.
Connected D2 pin 1 to Net-(D1-A).
Connected D2 pin 2 to Net-(D1-K).
Updated D2 unit metadata.
Added D3 (footprint 'LED_SMD:LED_1206_3216Metric').
Changed REF** reference designator to D3.
Connected J5 pin 1 to AC_L.
Updated J2 sheetname to '/'.
Added J3 (footprint 'PCM_SparkFun-Connector:USB-C_16').
Updated J2 unit metadata.
Connected J2 pin 2 to /SWDIO.
Add net /SWDIO.
Connected J2 pin 4 to GND.
Connected J2 pin 1 to 3.3VD.
Connected J2 pin 3 to /SWCLK.
Add net /SWCLK.
Updated J2 footprint filters to 'Connector*:*_1x??_*'.
Updated J2 sheetfile to 'Energy_Meter.kicad_sch'.
Changed REF** reference designator to J3.
Updated J2 fields.
Updated J2 symbol association from  to /1db41e04-ab2b-4bfe-b724-95b9444f2672.
Changed J2 value from PinHeader_1x04_P2.54mm_Horizontal to Conn_01x04_Pin.
Changed REF** reference designator to J2.
Added J2 (footprint 'Connector_PinHeader_2.54mm:PinHeader_1x04_P2.54mm_Horizontal').
Updated J1 unit metadata.
Connected J1 pin 2 to Net-(J1-Pad2).
Connected J1 pin 1 to Net-(C8-Pad1).
Connected J1 pin 2 to Net-(J1-Pad2).
Connected J1 pin 3 to unconnected-(J1-Pad3).
Add net unconnected-(J3-NC-PadA8).
Connected J3 pin GND to GND.
Connected J3 pin A7 to /USB_C-.
Connected J3 pin B6 to /USB_C+.
Connected J3 pin NC1 to unconnected-(J3-NC-PadNC1).
Add net unconnected-(J3-NC-PadNC1).
Connected J3 pin NC3 to unconnected-(J3-NC-PadNC3).
Add net unconnected-(J3-NC-PadNC3).
Connected J3 pin B5 to Net-(J3-CC2).
Add net Net-(J3-CC2).
Connected J3 pin A8 to unconnected-(J3-NC-PadA8).
Connected J3 pin B7 to /USB_C-.
Add net /USB_C-.
Connected J3 pin A6 to /USB_C+.
Add net /USB_C+.
Updated J3 footprint filters to 'USB*C*Receptacle*'.
Updated J3 sheetfile to 'Energy_Meter.kicad_sch'.
Updated J3 sheetname to '/'.
Updated J3 fields.
Updated J3 symbol association from  to /64ae0d8f-e10a-405a-8812-469545ec49ea.
Changed J3 value from USB-C_16 to USB_C_Receptacle.
Warning: No net found for component J6 pad SH3 (no pin SH3 in symbol).
Warning: No net found for component SW4 pad 7 (no pin 7 in symbol).
Warning: No net found for component J6 pad SH4 (no pin SH4 in symbol).
Warning: No net found for component J6 pad SH1 (no pin SH1 in symbol).
Warning: No net found for component J6 pad SH2 (no pin SH2 in symbol).
Warning: No net found for component J5 pad SH4 (no pin SH4 in symbol).
Warning: No net found for component J5 pad SH1 (no pin SH1 in symbol).
Warning: No net found for component J5 pad SH2 (no pin SH2 in symbol).
Warning: No net found for component J7 pad SH3 (no pin SH3 in symbol).
Warning: No net found for component J7 pad SH1 (no pin SH1 in symbol).
Warning: No net found for component J7 pad SH2 (no pin SH2 in symbol).
Warning: No net found for component J7 pad SH4 (no pin SH4 in symbol).
Warning: No net found for component J5 pad SH3 (no pin SH3 in symbol).
Warning: No net found for component J8 pad SH1 (no pin SH1 in symbol).
Warning: No net found for component J8 pad SH2 (no pin SH2 in symbol).
Warning: No net found for component J8 pad SH4 (no pin SH4 in symbol).
Warning: No net found for component J8 pad SH3 (no pin SH3 in symbol).
Warning: No net found for component DS1 pad SH1 (no pin SH1 in symbol).
Warning: No net found for component DS1 pad SH2 (no pin SH2 in symbol).
Warning: No net found for component SW4 pad 6 (no pin 6 in symbol).
Error: J5 pad SH not found in Components_Footprint:POMONA_73096-2.
Error: J6 pad SH not found in Components_Footprint:POMONA_73096-2.
Error: J7 pad SH not found in Components_Footprint:POMONA_73096-2.
Error: J8 pad SH not found in Components_Footprint:POMONA_73096-2.

Info: Total warnings: 20, errors: 4.

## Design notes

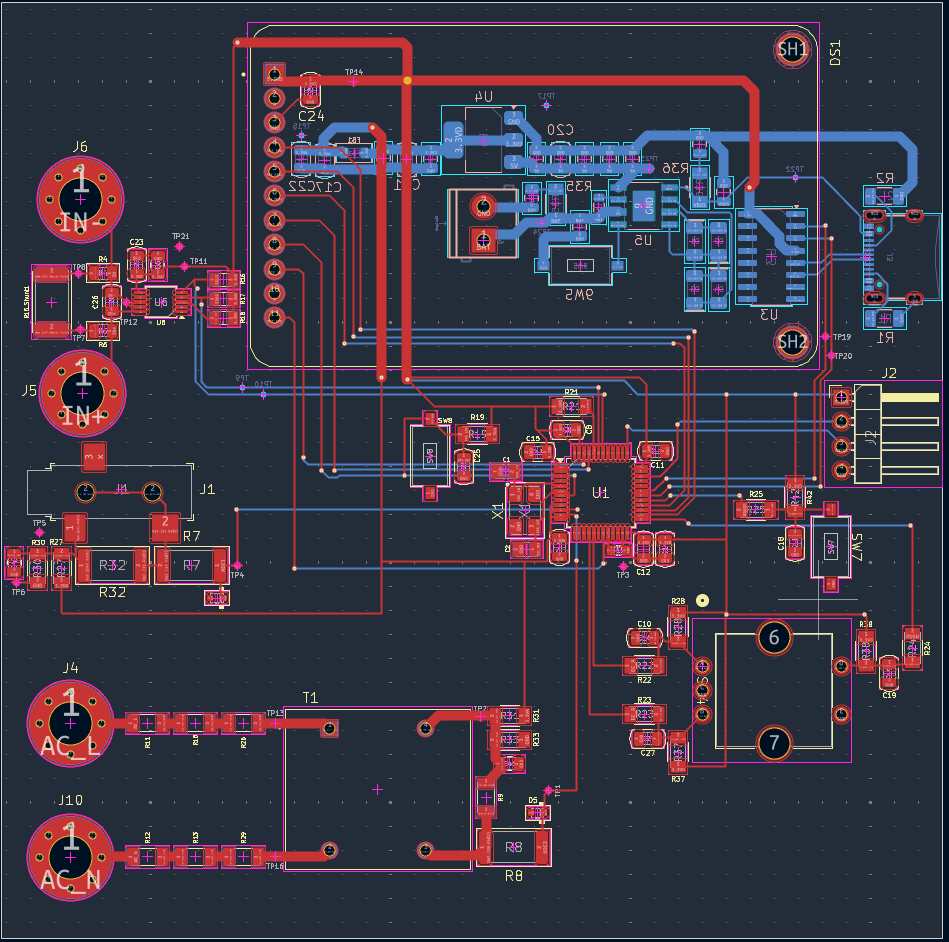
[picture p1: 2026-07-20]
Screenshot_2026-07-19_09-14-36.png

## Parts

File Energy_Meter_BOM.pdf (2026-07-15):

Reference | Qty | Value | Package | Part Number
C33,C35 | 2 | 22pF | RADIAL-2 TDK | IC289
T1 | 1 | ZMPT101B | None | K12_38
R15_Shunt1 | 1 | 0.001_1%_5W | None | SP004958
DS1 | 1 | 4311 | None | 1528-4311-ND
U5 | 1 | IP5306 | eSOP8 INJOINIC | NM01431
R16,R17,R18,R19,R20,R21 | 6 | 20k_1206 | 3216-2 Panasonic | 603-AE0402BR-0720KL
R4_Burden1 | 1 | 360_1206 | 3116 Yageo | 603-AC1206FR-074K75L
R10_Burden1 | 1 | 33_0805 | 805 KOA | 71-CRCW0805-30.1-E3
Y1 | 1 | Crystal_8MHz | | CRY00025
U4 | 1 | AMS1117-3.3 | | E3600504
U3 | 1 | CH340C | | IC36480
U2 | 1 | INA238 | | 595-INA238AIDGSR
U1 | 1 | STM32F103C8Tx | | STM32F103C8T6TR
TP1,TP2,TP3,TP4,TP5,TP6,TP7,TP8,TP9 21 | 0.5mm
SW6 | 1 | SW_Push | | PTS636 SK25 SMTR LFS
SW5 | 1 | Push_Button
SW4 | 1 | EC11E15244G1 | | E3600225
SW3 | 1 | SW_SPDT
SW2 | 1 | Switch_Tactile_CnK
R35 | 1 | 2 | | DAT9014
R28 | 1 | 2Î© | | RC1206FR-072RL
R25 | 1 | 1.5k_0603 | | RC0603FR-071K5L
R15,R26,R27,R29,R30,R31,R33 | 7 | 10k
R11,R12,R13 | 3 | 4.7k
R9,R24 | 2 | 1k
R7,R8,R22,R23 | 4 | 470k
R5,R14 | 2 | 10 | | DAT9032
R4,R10,R32,R34 | 4 | 100 | | IC246
R1,R2 | 2 | 5.1K | | ERJ-8GEYJ512V
L2 | 1 | 1 ÂµH | | TMPC0502HP-1R0MG-D ERJ-8GEYJ512V
J9 | 1 | 3.5mm
J4,J5,J6,J10 | 4 | Conn_01x01 | | 565-73096-2
J3 | 1 | USB_C_Receptacle | | IC36686
J2 | 1 | Conn_01x04_Pin
J1 | 1 Conn_Jack_Stereo_3.5mm_SMD_RA
FB1 | 1 | FerriteBead | | CL07788
D6,D7 | 2 | ESD5Z3V3 | | 637-ESD5Z3V3
D5,D8,D9,D10 | 4 | Blue LED | | 5988291107F
C40 | 1 | 10uF | | IC3412
C36,C37,C38 | 3 | 22 uF | | CL31A226KAHNNNE
C27,C34,C39 | 3 | 10 uF | | C1206C106M3PAC7800
C20,C21 | 2 | 10nF_0603_25V | | 06035C103KAT2A
C15,C16,C17,C18,C19 | 5 | 100nF_0603_16V | | 0603YC104KAT2A
C14 | 1 | 0.1uF | | IC297
C13,C22 | 2 | 1uF_0603_25V | | GRM188R61E105KA12D
C12 | 1 | 0.1uF_0603_16V | | 0603YC104KAT2A
C10,C23,C25,C26,C28,C29,C30,C31,C32 9 | 100nF_Ceramic
C8,C9,C11,C24 | 4 | 10uF_16V

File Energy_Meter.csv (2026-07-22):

Reference | Qty | Value | Package | Part Number
T1 | 1 | ZMPT101B | None
R15_Shunt1 | 1 | 0.001_1%_5W | None
DS1 | 1 | 4311 | None
U5 | 1 | IP5306 | eSOP8 INJOINIC
R5,R10,R11,R12,R13,R14 | 6 | 20k_1206 | 3216-2 Panasonic
R9 | 1 | 360_1206 | 3116 Yageo
R16,R17,R18 | 3 | 4.7k_0805 | 2012 Stackpole
C1,C2 | 2 | 22pF_0805 | 0805 Kemet
X1 | 1 | SMD5032-4
U6 | 1 | INA226
U4 | 1 | AMS1117-3.3 |  | AMS1117-3.3
U3 | 1 | CH340G
U1 | 1 | STM32F103C8Tx |  | STM32F103C8T6TR
TP1,TP2,TP3,TP4,TP5,TP6,TP7,TP8,TP9,TP10,TP11,TP12,TP13,TP14,TP15,TP16,TP17,TP18,TP19,TP20,TP21,TP22,TP23,TP24,TP25,TP26,TP27 | 27 | 0.5mm
SW6,SW7,SW8 | 3 | SW_Push |  | PTS636 SK25 SMTR LFS
SW4 | 1 | EC11E15244G1
R35,R36 | 2 | 2
R32 | 1 | 33R_1%_2512
R27,R30,R31,R33 | 4 | 470k_1206
R22,R23,R24,R25 | 4 | 100R_1206
R19,R21,R28,R37,R38,R42 | 6 | 10k_1206
R7,R8 | 2 | 1k_2512
R4,R6 | 2 | 10R_0805
R3 | 1 | 10k
R1,R2 | 2 | 5.1K |  | ERJ-8GEYJ512V
L1 | 1 | 1.0uH
J9 | 1 | 3.5mm
J4,J5,J6,J10 | 4 | Conn_01x01
J3 | 1 | USB_C_Receptacle
J2 | 1 | Conn_01x04_Pin
J1 | 1 | Conn_Jack_Stereo_3.5mm_SMD_RA
FB1 | 1 | FerriteBead
D5,D6 | 2 | PESD5Z3.3
D1,D2,D3,D4 | 4 | Red
C15,C17 | 2 | 10nF_0805
C13,C34,C36,C37,C38,C39,C41,C43 | 8 | 10uF
C8,C10,C11,C12,C14,C16,C18,C19,C20,C21,C22,C23,C24,C25,C26,C27 | 16 | 100nF_0805
C4,C5,C9 | 3 | 22uF
C3,C6 | 2 | 1.0uF

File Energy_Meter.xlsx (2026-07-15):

Reference | Qty | Value | Package | Part Number
C33,C35 | 2 | 22pF | RADIAL-2 TDK | C031508
T1 | 1 | ZMPT101B | None | B070610
R15_Shunt1 | 1 | 0.001_1%_5W | None | SP004958
DS1 | 1 | 4311 | None | 1528-4311-ND
U5 | 1 | IP5306 | eSOP8 INJOINIC | A112602
R16,R17,R18,R19,R20,R21 | 6 | 20k_THT | 3216-2 Panasonic
R4_Burden1 | 1 | 360_1%_THT | 3116 Yageo | CL11021
R10_Burden1 | 1 | 33_THT_1% | 805 KOA | NM03387
Y1 | 1 | Crystal_8MHz |  | CRY00025
U4 | 1 | AMS1117-3.3 |  | K030106
U3 | 1 | CH340G |  | IC36480
U2 | 1 | INA238 |  | 595-INA238AIDGSR
U1 | 1 | STM32F103C8Tx |  | STM32F103C8T6TR
TP1,TP2,TP3,TP4,TP5,TP6,TP7,TP8,TP9,TP10,TP11,TP12,TP14,TP15,TP17,TP19,TP20,TP21,TP22,TP23,TP24 | 21 | 0.5mm
SW6 | 1 | SW_Push |  | NM00689
SW5 | 1 | Push_Button |  | NM00689
SW4 | 1 | EC11E15244G1 |  | E3600225
SW3 | 1 | SW_SPDT
SW2 | 1 | Switch_Tactile_CnK |  | NM00689
R35 | 1 | 2 |  | G090606
R28 | 1 | 2 |  | G090606
R25 | 1 | 1.5k_THT |  | NM01863
R15,R26,R27,R29,R30,R31,R33 | 7 | 10k
R11,R12,R13 | 3 | 4.7k
R9,R24 | 2 | 1k
R7,R8,R22,R23 | 4 | 470k
R5,R14 | 2 | 10 |  | NM01763
R4,R10,R32,R34 | 4 | 100 |  | NM01830
R1,R2 | 2 | 5.1K |  | NM04358
L2 | 1 | 1 µH |  | G080407
J9 | 1 | 3.5mm
J4,J5,J6,J10 | 4 | Conn_01x01 |  | 565-73096-2
J3 | 1 | USB_C_Receptacle |  | CL11134
J2 | 1 | Conn_01x04_Pin
J1 | 1 | Conn_Jack_Stereo_3.5mm_SMD_RA |  | B061011
FB1 | 1 | FerriteBead |  | G050210
D6,D7 | 2 | ESD5Z3V3 |  | G080808
D5,D8,D9,D10 | 4 | Blue LED |  | NM02114
C40 | 1 | 10uF |  | NM00616
C36,C37,C38 | 3 | 22 uF
C27,C34,C39 | 3 | 10 uF |  | NM00616
C20,C21 | 2 | 10nF_0603_25V
C15,C16,C17,C18,C19 | 5 | 100nF_0603_16V
C14 | 1 | 0.1uF
C13,C22 | 2 | 1uF_0603_25V
C12 | 1 | 0.1uF_0603_16V
C10,C23,C25,C26,C28,C29,C30,C31,C32 | 9 | 100nF_Ceramic
C8,C9,C11,C24 | 4 | 10uF_16V

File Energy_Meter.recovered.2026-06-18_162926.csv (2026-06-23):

Reference | Qty | Value | DNP | Exclude from BOM | Exclude from Board | Footprint | Datasheet
C1,C2,C3 | 3 | 10 uF |  |  |  | Capacitor_SMD:C_1206_3216Metric | https://connect.kemet.com:7667/gateway/IntelliData-ComponentDocumentation/1.0/download/datasheet/C1206C106M3PACTU
C4,C6,C7 | 3 | 22 uF |  |  |  | Capacitor_SMD:C_1206_3216Metric | https://www.lcsc.com/datasheet/lcsc_datasheet_2304140030_Samsung-Electro-Mechanics-CL31A226KAHNNNE_C12891.pdf
C5 | 1 | 10uF |  |  |  | PCM_SparkFun-Capacitor:C_1210_3225Metric | https://cdn.sparkfun.com/assets/8/a/4/a/5/Kemet_Capacitor_Datasheet.pdf
C8,C9,C11,C24 | 4 | 10uF_16V |  |  |  | Capacitor_THT:CP_Radial_D5.0mm_P2.00mm
C10,C23,C25 | 3 | 100nF_Ceramic |  |  |  | Capacitor_THT:C_Disc_D5.0mm_W2.5mm_P2.50mm
C12 | 1 | 0.1uF_0603_16V |  |  |  | PCM_4ms_Capacitor:C_0603
C13,C22 | 2 | 1uF_0603_25V |  |  |  | Capacitor_SMD:C_0603_1608Metric
C14 | 1 | 0.1uF |  |  |  | PCM_SparkFun-Capacitor:C_0603_1608Metric | https://cdn.sparkfun.com/assets/8/a/4/a/5/Kemet_Capacitor_Datasheet.pdf
C15,C16,C17,C18,C19 | 5 | 100nF_0603_16V |  |  |  | Capacitor_SMD:C_0603_1608Metric
C20,C21 | 2 | 10nF_0603_25V |  |  |  | Capacitor_SMD:C_0603_1608Metric
D1,D2,D3,D4 | 4 | Blue LED |  |  |  | LED_SMD:LED_1206_3216Metric | https://s3-us-west-2.amazonaws.com/catsy.557/Dialight_CBI_data_598-1206_Apr2018.pdf
D6,D7 | 2 | ESD5Z3V3 |  |  |  | PCM_Diode_SMD_AKL:D_SOD-523 | https://www.tme.eu/Document/d13ef8e94b33d3a9cbff2cf36d4aeefa/esd5z2v5.pdf
FB1 | 1 | FerriteBead |  |  |  | Components_Footprint:XFMR_ZMPT101B
J1 | 1 | Conn_Jack_Stereo_3.5mm_SMD_RA |  |  |  | PCM_fab:Conn_Jack_Stereo_3.5mm_CUI_SJ-3523-SMT-TR | https://www.cuidevices.com/product/resource/sj-352x-smt.pdf
J2 | 1 | Conn_01x04_Socket |  |  |  | Connector_PinSocket_1.00mm:PinSocket_1x04_P1.00mm_Vertical
J3 | 1 | USB_C_Receptacle |  |  |  | PCM_SparkFun-Connector:USB-C_16 | https://www.usb.org/sites/default/files/documents/usb_type-c.zip
J5,J6,J7,J8 | 4 | Conn_01x01_Shielded |  |  |  | Connector:Banana_Jack_1Pin
L1 | 1 | 1 µH |  |  |  | Inductor_SMD:L_Sunlord_SWPA6028S | https://www.lcsc.com/datasheet/lcsc_datasheet_2009171438_TAI-TECH-TMPC0502HP-1R0MG-D_C305205.pdf
R1,R2 | 2 | 5.1K |  |  |  | Resistor_SMD:R_1206_3216Metric | https://industrial.panasonic.com/ww/products/pt/general-purpose-chip-resistors/models/ERJ-8GEYJ512V
R3 | 1 | 2Ω |  |  |  | Resistor_SMD:R_1206_3216Metric | https://www.lcsc.com/datasheet/lcsc_datasheet_2304140030_YAGEO-RC1206FR-072RL_C137316.pdf
R4_Burden1 | 1 | 360_1206 |  |  |  | Components_Footprint:RESC3116X65N
R5,R14 | 2 | 10 |  |  |  | PCM_SparkFun-Resistor:R_1206_3216Metric | https://www.vishay.com/docs/20035/dcrcwe3.pdf
R6 | 1 | 2 |  |  |  | PCM_fab:R_1206
R7,R8,R22,R23 | 4 | 470k |  |  |  | Resistor_THT:R_Axial_DIN0207_L6.3mm_D2.5mm_P10.16mm_Horizontal
R9,R24 | 2 | 1k |  |  |  | Resistor_THT:R_Axial_DIN0207_L6.3mm_D2.5mm_P10.16mm_Horizontal
R10 | 1 | 33 |  |  |  | PCM_fab:R_1206
R11,R12,R13 | 3 | 4.7k |  |  |  | PCM_SparkFun-Resistor:R_0603_1608Metric | https://www.vishay.com/docs/20035/dcrcwe3.pdf
R15,R26,R27 | 3 | 10k |  |  |  | Resistor_THT:R_Axial_DIN0207_L6.3mm_D2.5mm_P10.16mm_Horizontal
R15_Shunt1 | 1 | 0.001_1%_5W |  |  |  | Components_Footprint:RESC6331X88N
R16,R17,R18,R19,R20,R21 | 6 | 20k_1206 |  |  |  | Components_Footprint:RES_ERA8ARB203V
R25 | 1 | 1.5k_0603 |  |  |  | Capacitor_SMD:C_0603_1608Metric
SW1 | 1 | SW_Push |  |  |  | Button_Switch_SMD:SW_Tactile_SPST_NO_Straight_CK_PTS636Sx25SMTRLFS | https://www.ckswitches.com/media/2779/pts636.pdf
SW2 | 1 | Switch_Tactile_CnK |  |  |  | PCM_fab:Button_CnK_PTS636.0_6x3.5mm | https://www.ckswitches.com/media/2779/pts636.pdf
SW3 | 1 | SW_SPDT |  |  |  | Components_Footprint:SOP127P600X165-9N
T1 | 1 | ZMPT101B |  |  |  | Components_Footprint:XFMR_ZMPT101B
U1 | 1 | STM32F103C8Tx |  |  |  | Package_QFP:LQFP-48_7x7mm_P0.5mm | https://www.st.com/resource/en/datasheet/stm32f103c8.pdf
U2 | 1 | INA238 |  |  |  | Package_SO:TSSOP-10_3x3mm_P0.5mm | https://www.ti.com/lit/ds/symlink/ina238.pdf
U4 | 1 | AMS1117-3.3 |  |  |  | Package_TO_SOT_SMD:SOT-223-3_TabPin2 | http://www.advanced-monolithic.com/pdf/ds1117.pdf
U5 | 1 | DM-OLED096-636 |  |  |  | Components_Footprint:MODULE_DM-OLED096-636
U6 | 1 | IP5306 |  |  |  | Components_Footprint:SOP127P600X165-9N | https://www.lcsc.com/datasheet/lcsc_datasheet_2411071421_INJOINIC-IP5306_C181692.pdf

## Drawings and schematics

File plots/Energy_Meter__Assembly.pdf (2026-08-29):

1 | 2 | 3 | 4 | 5 | 6

AB

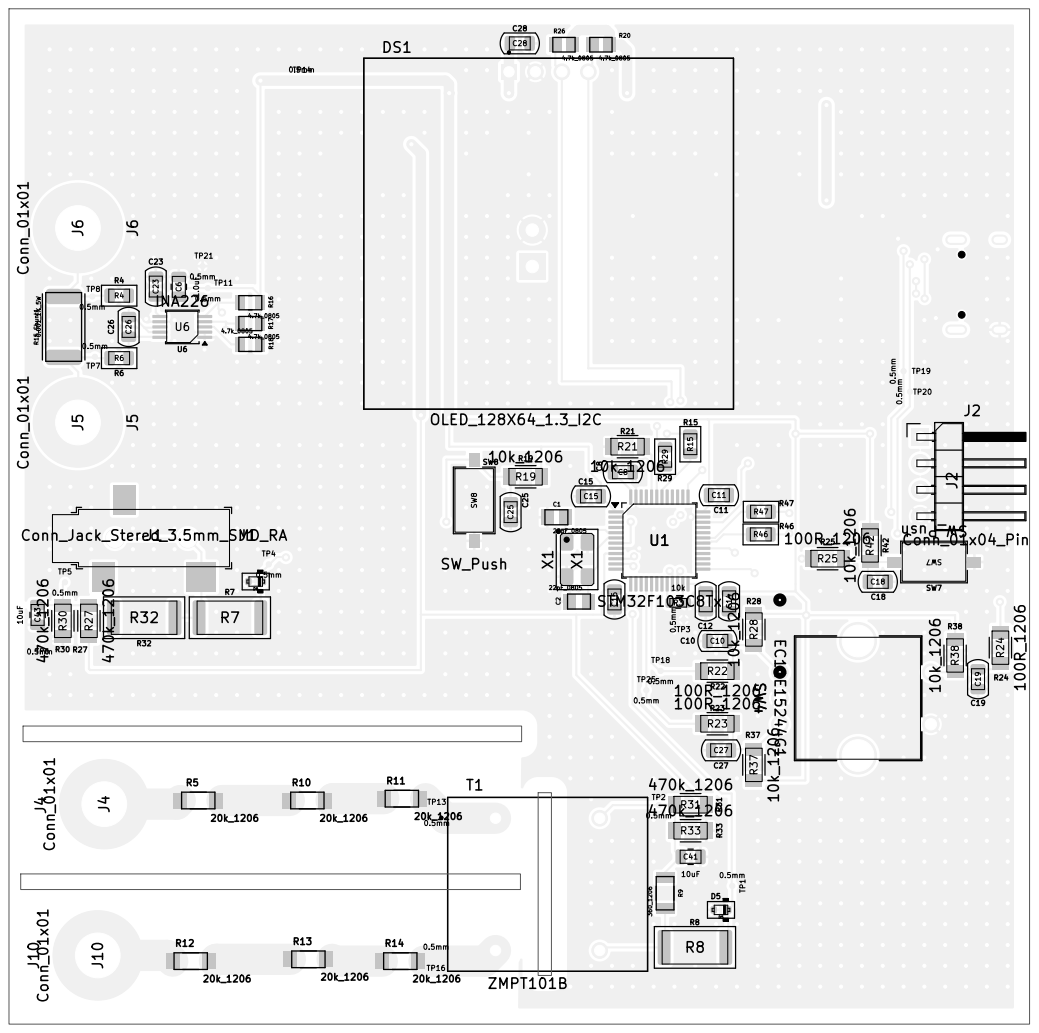
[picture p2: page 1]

Board2Pdf: Black And White TOP - Page 1/2

Sheet: Black And White TOP
File: Energy_Meter.kicad_pcb
Title:
KiCad E.D.A. 10.0.5

C24 | U4 | C21 | C22 U5 U3 | R36 R2

AB

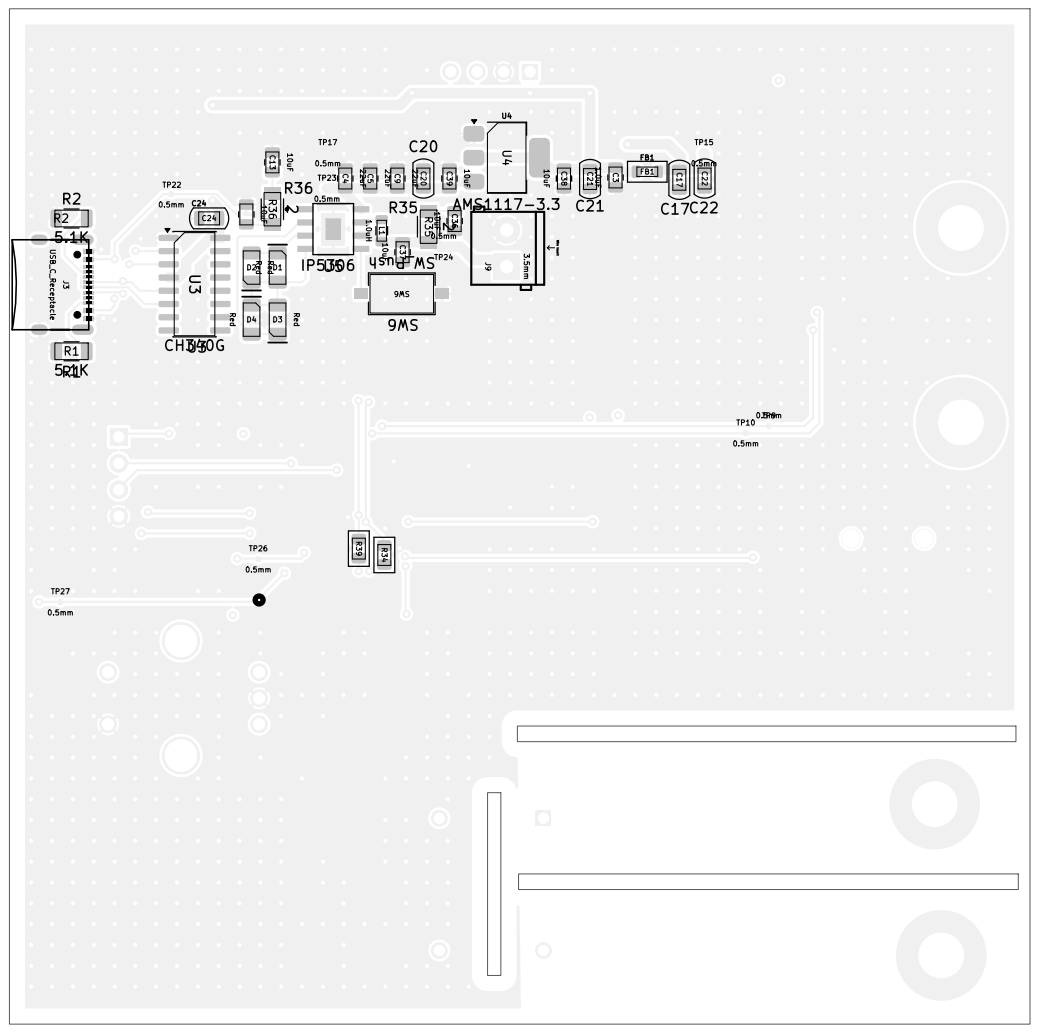
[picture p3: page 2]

Board2Pdf: Black And White BOT - Page 2/2

Sheet: Black And White BOT
File: Energy_Meter.kicad_pcb
Title:
KiCad E.D.A. 10.0.5

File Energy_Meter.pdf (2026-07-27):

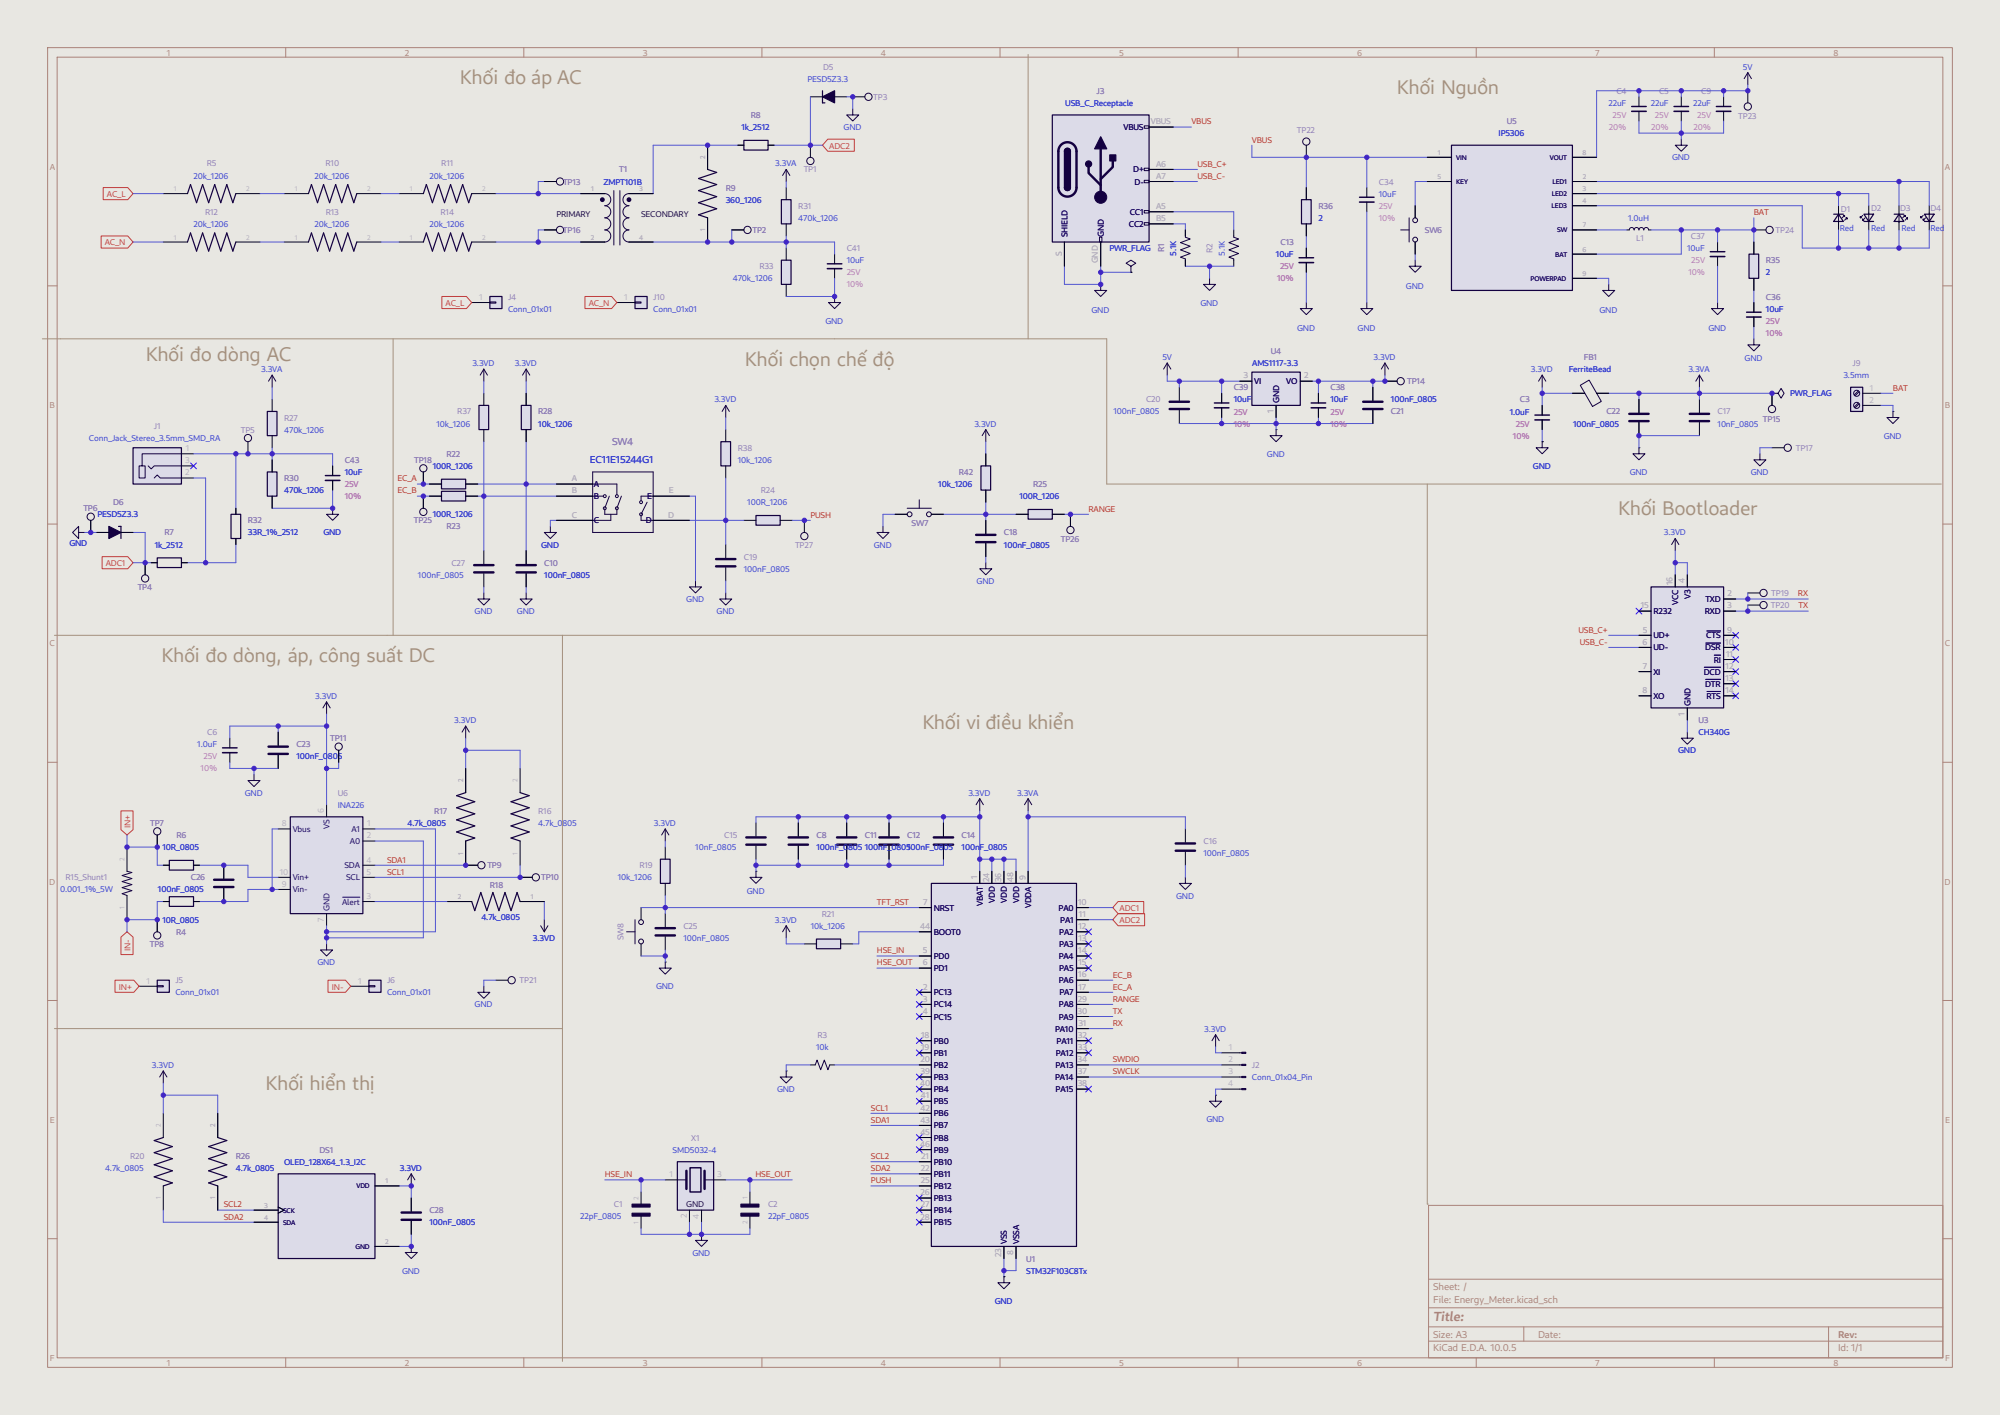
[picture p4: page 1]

Khối đo dòng, áp, công suất DC

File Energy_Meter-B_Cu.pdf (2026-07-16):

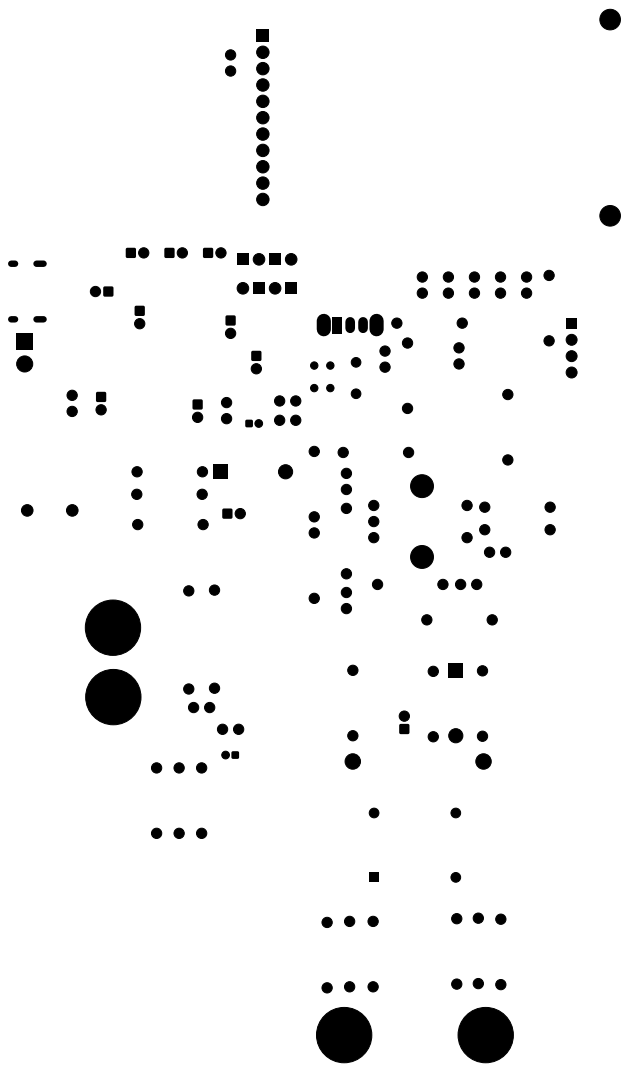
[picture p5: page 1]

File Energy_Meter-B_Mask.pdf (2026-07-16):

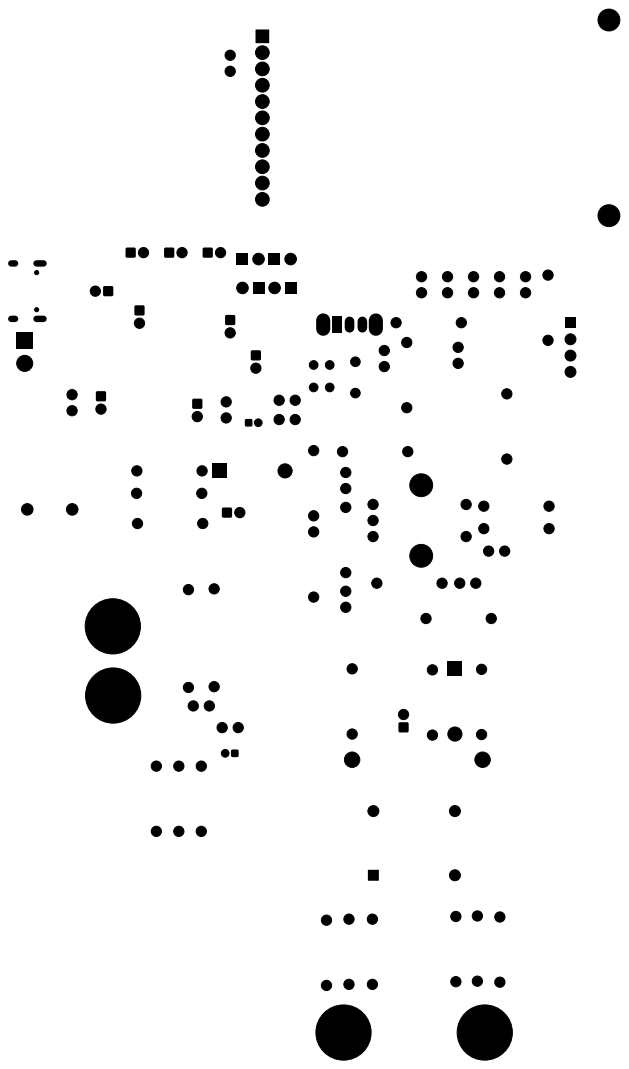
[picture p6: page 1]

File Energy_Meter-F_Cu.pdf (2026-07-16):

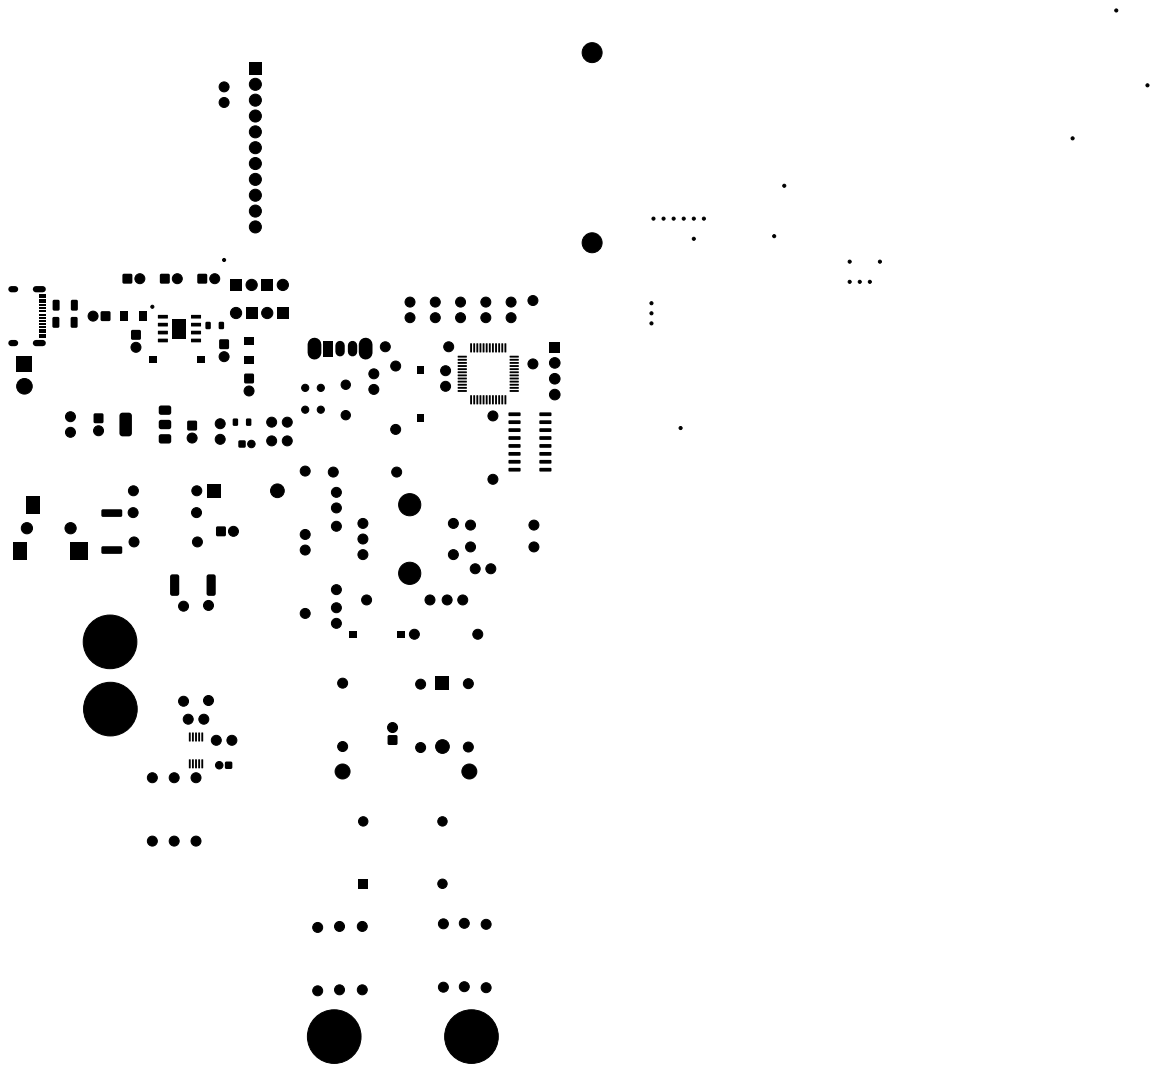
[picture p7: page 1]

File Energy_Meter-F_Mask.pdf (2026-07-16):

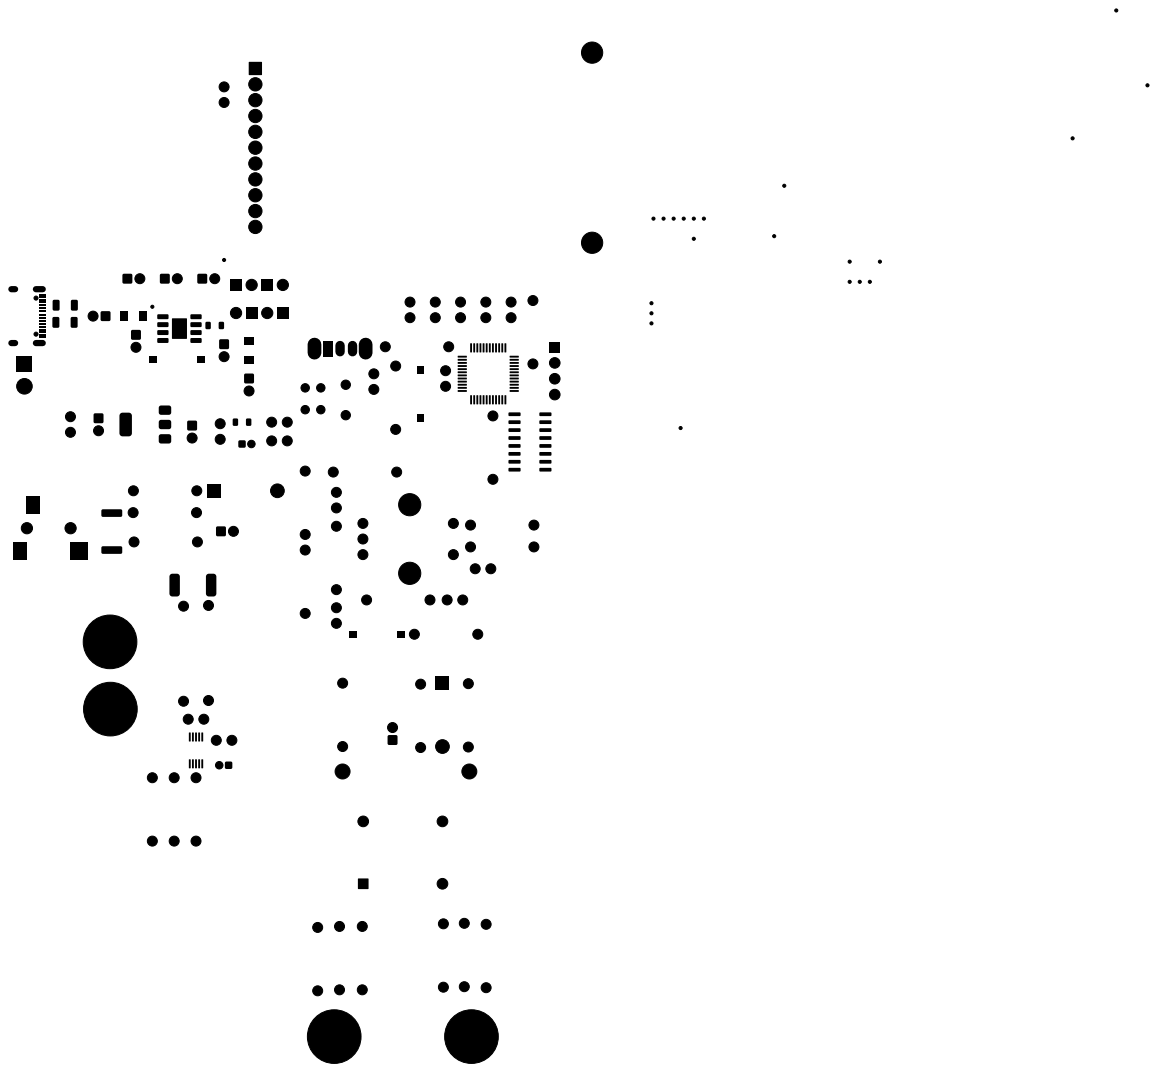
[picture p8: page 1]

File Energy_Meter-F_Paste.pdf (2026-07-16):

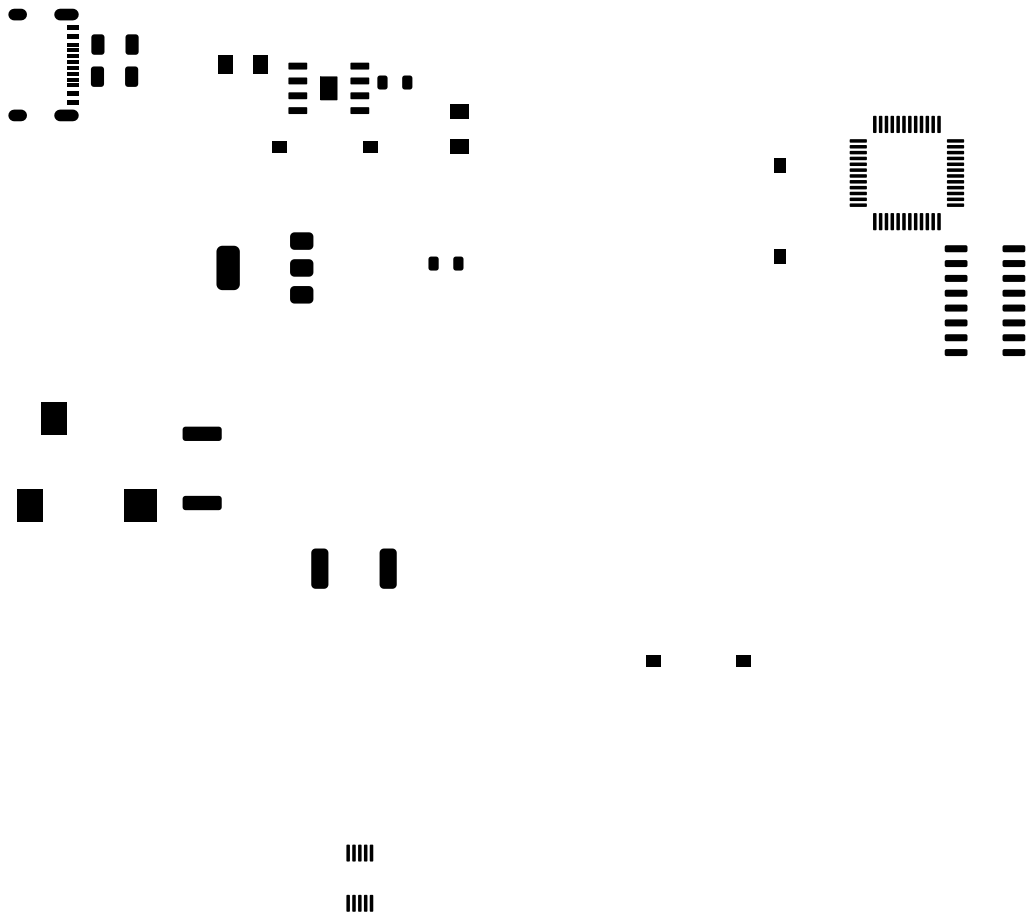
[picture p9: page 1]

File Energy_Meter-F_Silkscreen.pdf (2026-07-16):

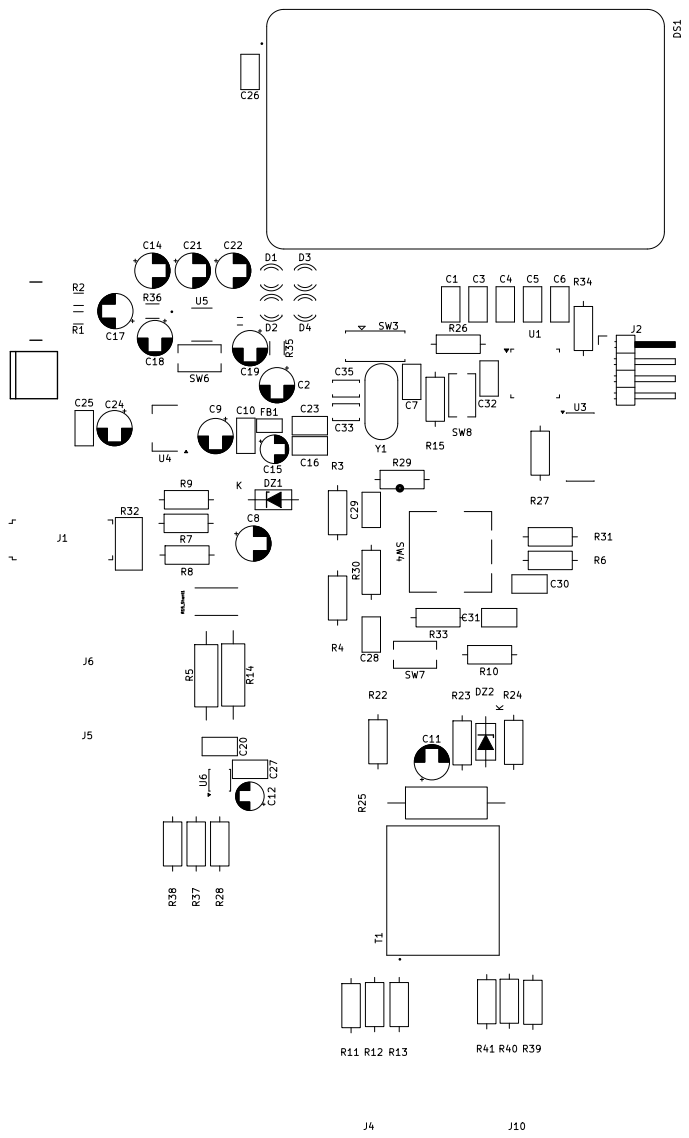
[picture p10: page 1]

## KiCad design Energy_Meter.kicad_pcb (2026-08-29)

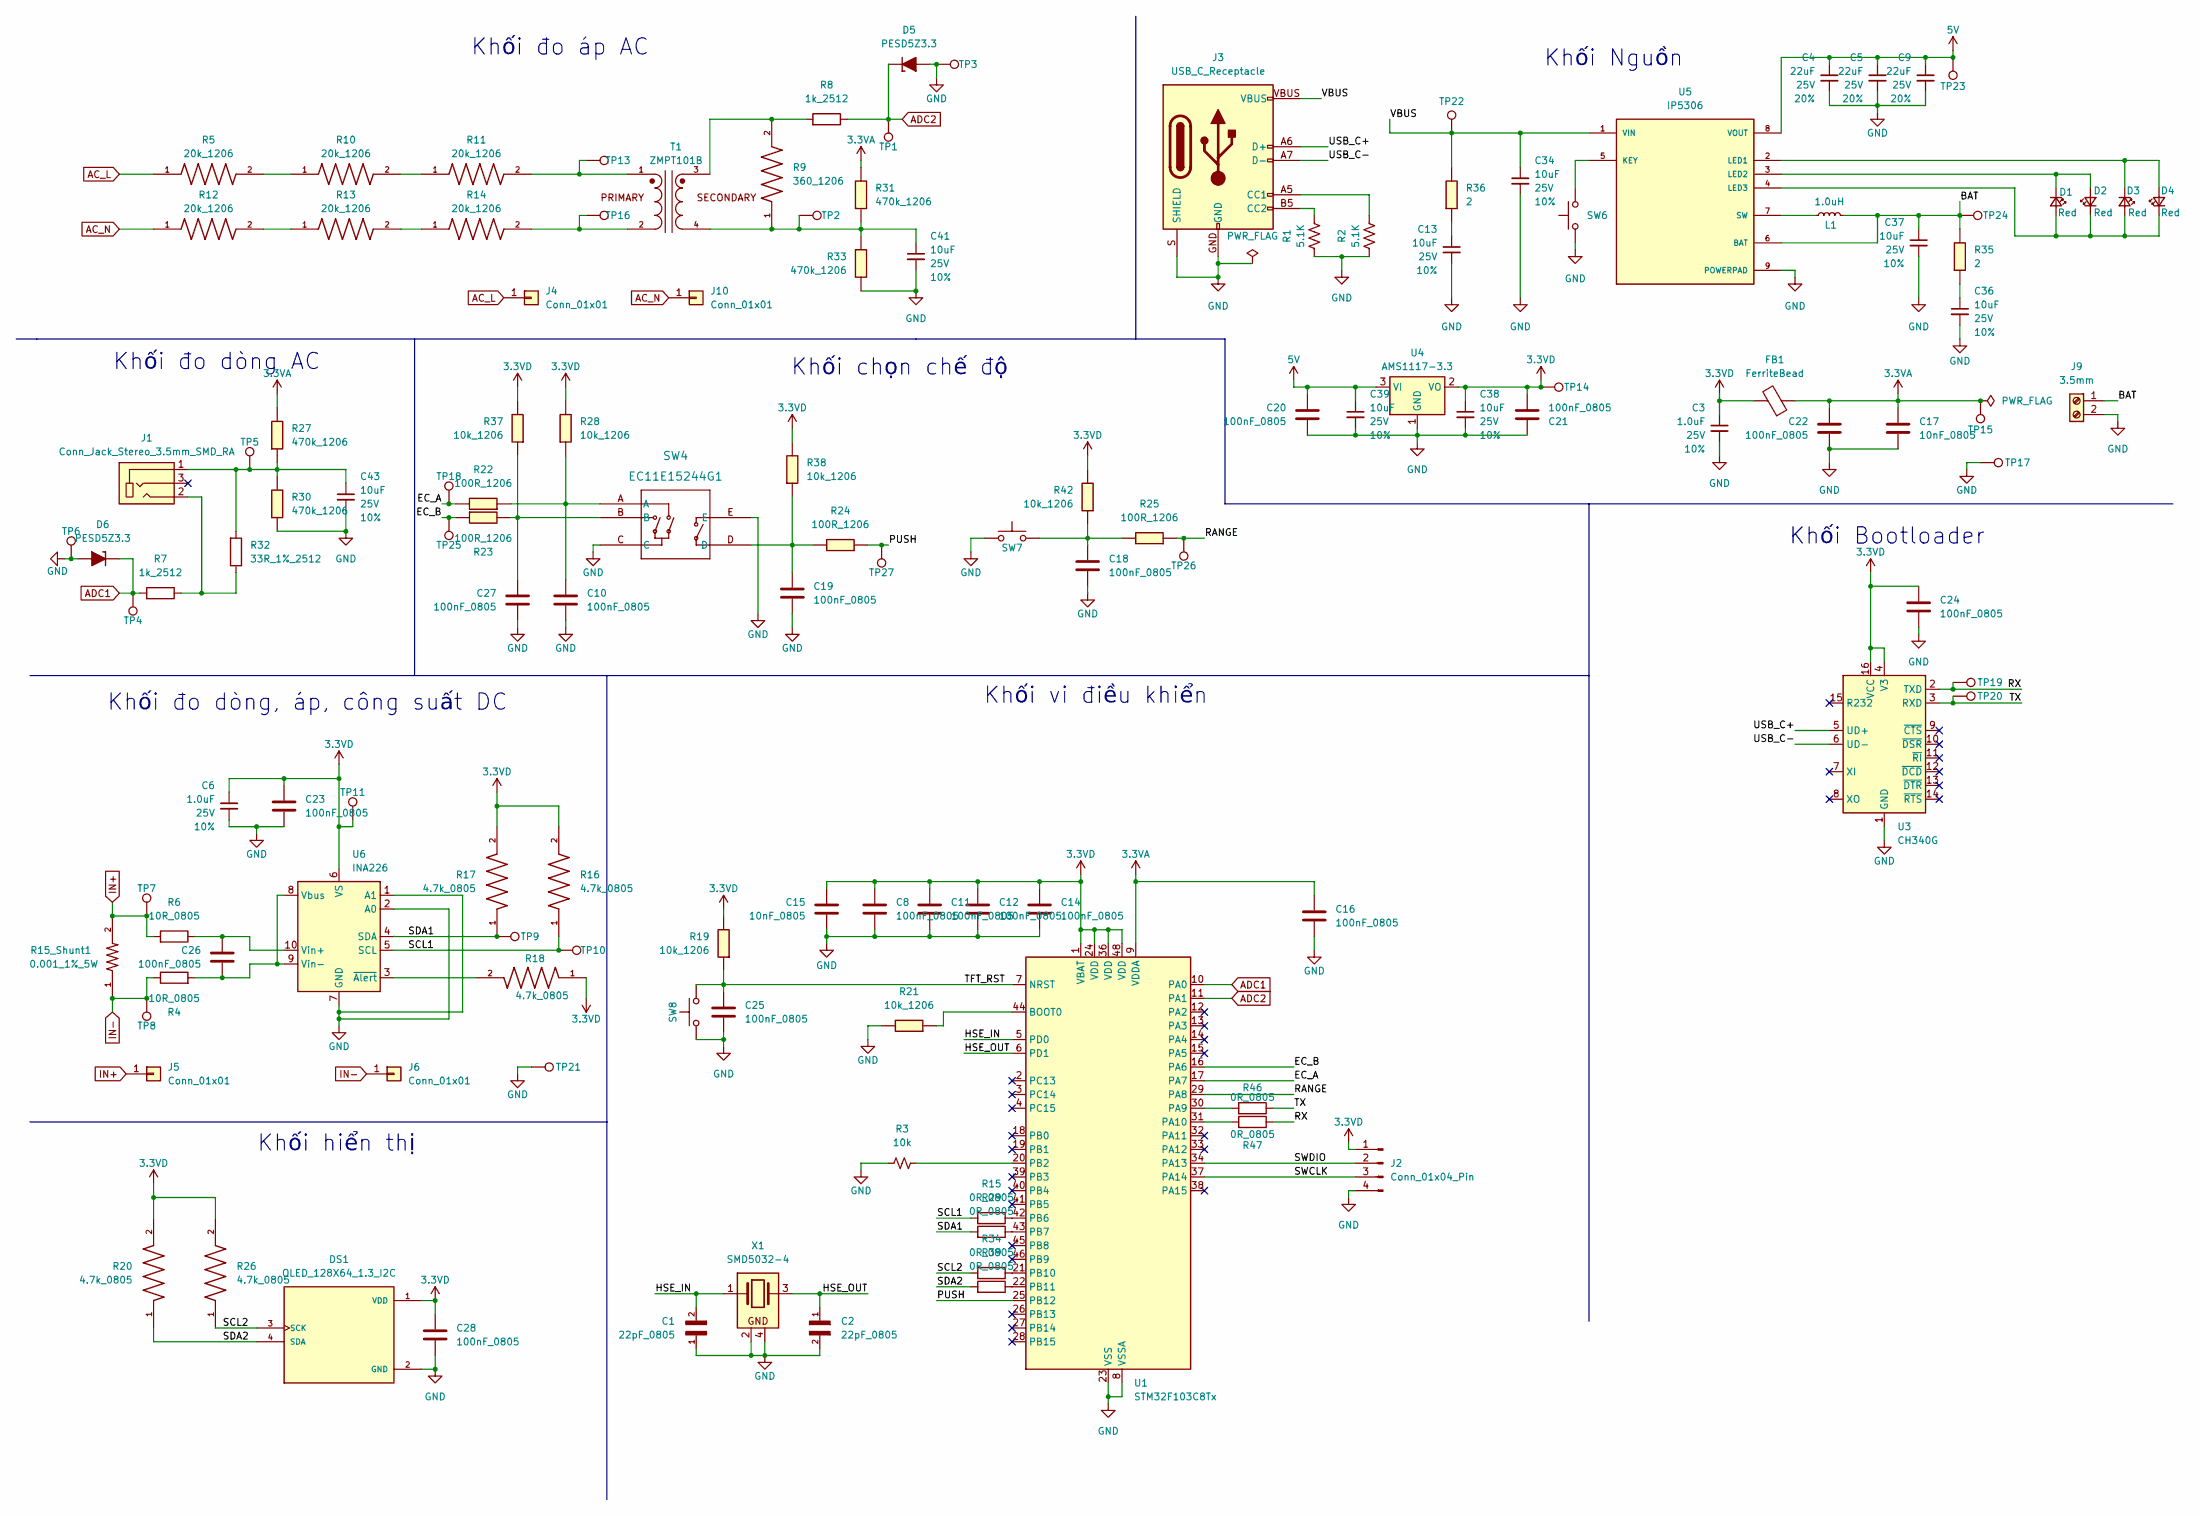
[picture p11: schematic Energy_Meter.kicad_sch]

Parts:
C1, C2: 22pF_0805; CAPC2012X88N
C3, C6: 1.0uF; C_0805_2012Metric; Voltage 25V; Tolerance 10%
C4, C5, C9: 22uF; C_0805_2012Metric; Voltage 25V; Tolerance 20%
C8, C10, C11, C12, C14, C16, C18, C19, C20, C21, C22, C23, C24, C25, C26, C27, C28: 100nF_0805; C_0805_2012Metric
C13, C34, C36, C37, C38, C39, C41, C43: 10uF; C_0805_2012Metric; Voltage 25V; Tolerance 10%
C15, C17: 10nF_0805; C_0805_2012Metric
D1, D2, D3, D4: Red; LED_1206_3216Metric_Red
D5, D6: PESD5Z3.3; D_SOD-523
DS1: OLED_128X64_1.3_I2C; LCD_OLED_128X64_1.3_I2C; PARTREV NA
FB1: FerriteBead; Ferrite_0805_2012Metric
J1: Conn_Jack_Stereo_3.5mm_SMD_RA; Conn_Jack_Stereo_3.5mm_CUI_SJ-3523-SMT-TR
J2: Conn_01x04_Pin; PinHeader_1x04_P2.54mm_Horizontal
J3: USB_C_Receptacle; USB-C_16
J4, J5, J6, J10: Conn_01x01; MountingHole_4.5mm_Pad
J9: 3.5mm; ScrewTerminal_1x02_P3.5mm_Horizontal_Black
L1: 1.0uH; 0805
R1, R2: 5.1K; R_1206_3216Metric; Part Number ERJ-8GEYJ512V
R3: 10k; R_0603_1608Metric
R4, R6: 10R_0805; R_0805_2012Metric
R5, R10, R11, R12, R13, R14: 20k_1206; RES_ERA8ARB203V; PARTREV 3/1/2020
R7, R8: 1k_2512; R_2512_6332Metric
R9: 360_1206; RESC3116X65N
R15, R29, R34, R39, R46, R47: 0R_0805; R_0805_2012Metric
R15_Shunt1: 0.001_1%_5W; RESC6331X88N
R16, R17, R18, R20, R26: 4.7k_0805; RESC2012X60N
R19, R21, R28, R37, R38, R42: 10k_1206; R_1206
R22, R23, R24, R25: 100R_1206; R_1206
R27, R30, R31, R33: 470k_1206; R_1206
R32: 33R_1%_2512; R_2512_6332Metric
R35, R36: 2; R_1206
SW4: EC11E15244G1; EC11E15244G1_AAL
SW6, SW7, SW8: SW_Push; SW_Tactile_SPST_NO_Straight_CK_PTS636Sx25SMTRLFS; Part Number PTS636 SK25 SMTR LFS
T1: ZMPT101B; XFMR_ZMPT101B; PARTREV NA
TP1, TP2, TP3, TP4, TP5, TP6, TP7, TP8, TP9, TP10, TP11, TP13, TP14, TP15, TP16, TP17, TP18, TP19, TP20, TP21, TP22, TP23, TP24, TP25, TP26, TP27: 0.5mm; TestPoint-0.5mm
U1: STM32F103C8Tx; LQFP-48_7x7mm_P0.5mm; Part Number STM32F103C8T6TR
U3: CH340G; SOIC-16_3.9x9.9mm_P1.27mm
U4: AMS1117-3.3; SOT-223-3_TabPin2; Part Number AMS1117-3.3
U5: IP5306; SOP127P600X165-9N; PARTREV 1.31
U6: INA226; TSSOP-10_3x3mm_P0.5mm
X1: SMD5032-4; Crystal_SMD_5032-4Pin_5.0x3.2mm

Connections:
3.3VA: C16.1, C17.1, C22.1, FB1.1, R27.1, R31.1, TP15.1 (1_1), U1.9 (VDDA)
3.3VD: C3.1, C6.1, C8.1, C11.1, C12.1, C14.1, C15.1, C21.2, C23.1, C24.1, C28.1, C38.1, DS1.1 (VDD), FB1.2, J2.1, R16.2, R17.2, R18.1, R19.1, R20.2, R26.2, R28.1, R37.1, R38.1, R42.1, TP11.1 (1_1), TP14.1 (1_1), U1.1 (VBAT), U1.24 (VDD), U1.36 (VDD), U1.48 (VDD), U3.4 (V3), U3.16 (VCC), U4.2 (VO), U6.6 (VS)
5V: C4.1, C5.1, C9.1, C20.1, C39.1, TP23.1 (1_1), U4.3 (VI), U5.8 (VOUT)
/BAT: C37.1, J9.1, L1.2, R35.1, TP24.1 (1_1), U5.6 (BAT)
/EC_A: R22.1, TP18.1 (1_1), U1.17 (PA7)
/EC_B: R23.2, TP25.1 (1_1), U1.16 (PA6)
/HSE_IN: C1.2, U1.5 (PD0), X1.1
/HSE_OUT: C2.1, U1.6 (PD1), X1.3
/PUSH: R24.2, TP27.1 (1_1), U1.25 (PB12)
/RANGE: R25.2, TP26.1 (1_1), U1.29 (PA8)
/RX: R47.2, TP19.1 (1_1), U3.2 (TXD)
/SCL1: R15.1, R16.1, TP10.1 (1_1), U6.5 (SCL)
/SCL2: DS1.3 (SCK), R26.1, R34.1
/SDA1: R17.1, R29.1, TP9.1 (1_1), U6.4 (SDA)
/SDA2: DS1.4 (SDA), R20.1, R39.1
/SWCLK: J2.3, U1.37 (PA14)
/SWDIO: J2.2, U1.34 (PA13)
/TFT_RST: C25.1, R19.2, SW8.2, U1.7 (NRST)
/TX: R46.2, TP20.1 (1_1), U3.3 (RXD)
/USB_C+: J3.A6 (D+), J3.B6 (D+), U3.5 (UD+)
/USB_C-: J3.A7 (D-), J3.B7 (D-), U3.6 (UD-)
/VBUS: C34.1, J3.VBUS, R36.1, TP22.1 (1_1), U5.1 (VIN)
AC_L: J4.1 (Pin_1_1), R5.1
AC_N: J10.1 (Pin_1_1), R12.1
ADC1: D6.1 (K), R7.1, TP4.1 (1_1), U1.10 (PA0)
ADC2: D5.1 (K), R8.2, TP1.1 (1_1), U1.11 (PA1)
GND: C1.1, C2.2, C3.2, C4.2, C5.2, C6.2, C8.2, C9.2, C10.2, C11.2, C12.2, C13.2, C14.2, C15.2, C16.2, C17.2, C18.2, C19.2, C20.2, C21.1, C22.2, C23.2, C24.2, C25.2, C27.2, C28.2, C34.2, C36.2, C37.2, C38.2, C39.2, C41.2, C43.2, D5.2 (A), D6.2 (A), DS1.2 (GND), J2.4, J3.GND, J3.S (SHIELD), J9.2, R1.1, R2.1, R3.1, R21.1, R30.2, R33.1, SW4.C, SW4.E, SW6.1, SW7.1, SW8.1, TP3.1 (1_1), TP6.1 (1_1), TP17.1 (1_1), TP21.1 (1_1), U1.8 (VSSA), U1.23 (VSS), U1.35 (VSS), U1.47 (VSS), U3.1 (GND), U4.1 (GND), U5.9 (POWERPAD), U6.1 (A1), U6.2 (A0), U6.7 (GND), X1.2, X1.4
IN+: J5.1 (Pin_1_1), R6.1, R15_Shunt1.2, TP7.1 (1_1)
IN-: J6.1 (Pin_1_1), R4.2, R15_Shunt1.1, TP8.1 (1_1)
unnamed: C10.1, R22.2, R28.2, SW4.A
unnamed: C13.1, R36.2
unnamed: C18.1, R25.1, R42.2, SW7.2
unnamed: C19.1, R24.1, R38.2, SW4.D
unnamed: C27.1, R23.1, R37.2, SW4.B
unnamed: C36.1, R35.2
unnamed: C41.1, R9.1, R31.2, R33.2, T1.4, TP2.1 (1_1)
unnamed: C43.1, J1.1, R27.2, R30.1, R32.1, TP5.1 (1_1)
unnamed: D1.2 (A), D2.1 (K), D3.2 (A), D4.1 (K), U5.4 (LED3)
unnamed: D1.1 (K), D2.2 (A), U5.3 (LED2)
unnamed: D3.1 (K), D4.2 (A), U5.2 (LED1)
unnamed: J1.2, R7.2, R32.2
unnamed: J3.A5 (CC1), R2.2
unnamed: J3.B5 (CC2), R1.2
unnamed: R8.1, R9.2, T1.3
unnamed: R5.2, R10.1
unnamed: R10.2, R11.1
unnamed: R11.2, T1.1, TP13.1 (1_1)
unnamed: R12.2, R13.1
unnamed: R13.2, R14.1
unnamed: R14.2, T1.2, TP16.1 (1_1)
unnamed: R21.2, U1.44 (BOOT0)
unnamed: R46.1, U1.30 (PA9)
unnamed: R47.1, U1.31 (PA10)
unnamed: R3.2, U1.20 (PB2)
unnamed: R15.2, U1.42 (PB6)
unnamed: R29.2, U1.43 (PB7)
unnamed: R34.2, U1.21 (PB10)
unnamed: R39.2, U1.22 (PB11)
unnamed: SW6.2, U5.5 (KEY)
unnamed: L1.1, U5.7 (SW)
unnamed: C26.2, R4.1, U6.8 (Vbus), U6.9 (Vin-)
unnamed: C26.1, R6.2, U6.10 (Vin+)
unnamed: R18.2, U6.3 (~Alert)

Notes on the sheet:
Khối Nguồn
Khối đo dòng AC
Khối chọn chế độ
Khối hiển thị
Khối Bootloader
Khối vi điều khiển
Khối đo áp AC
Khối đo dòng, áp, công suất DC

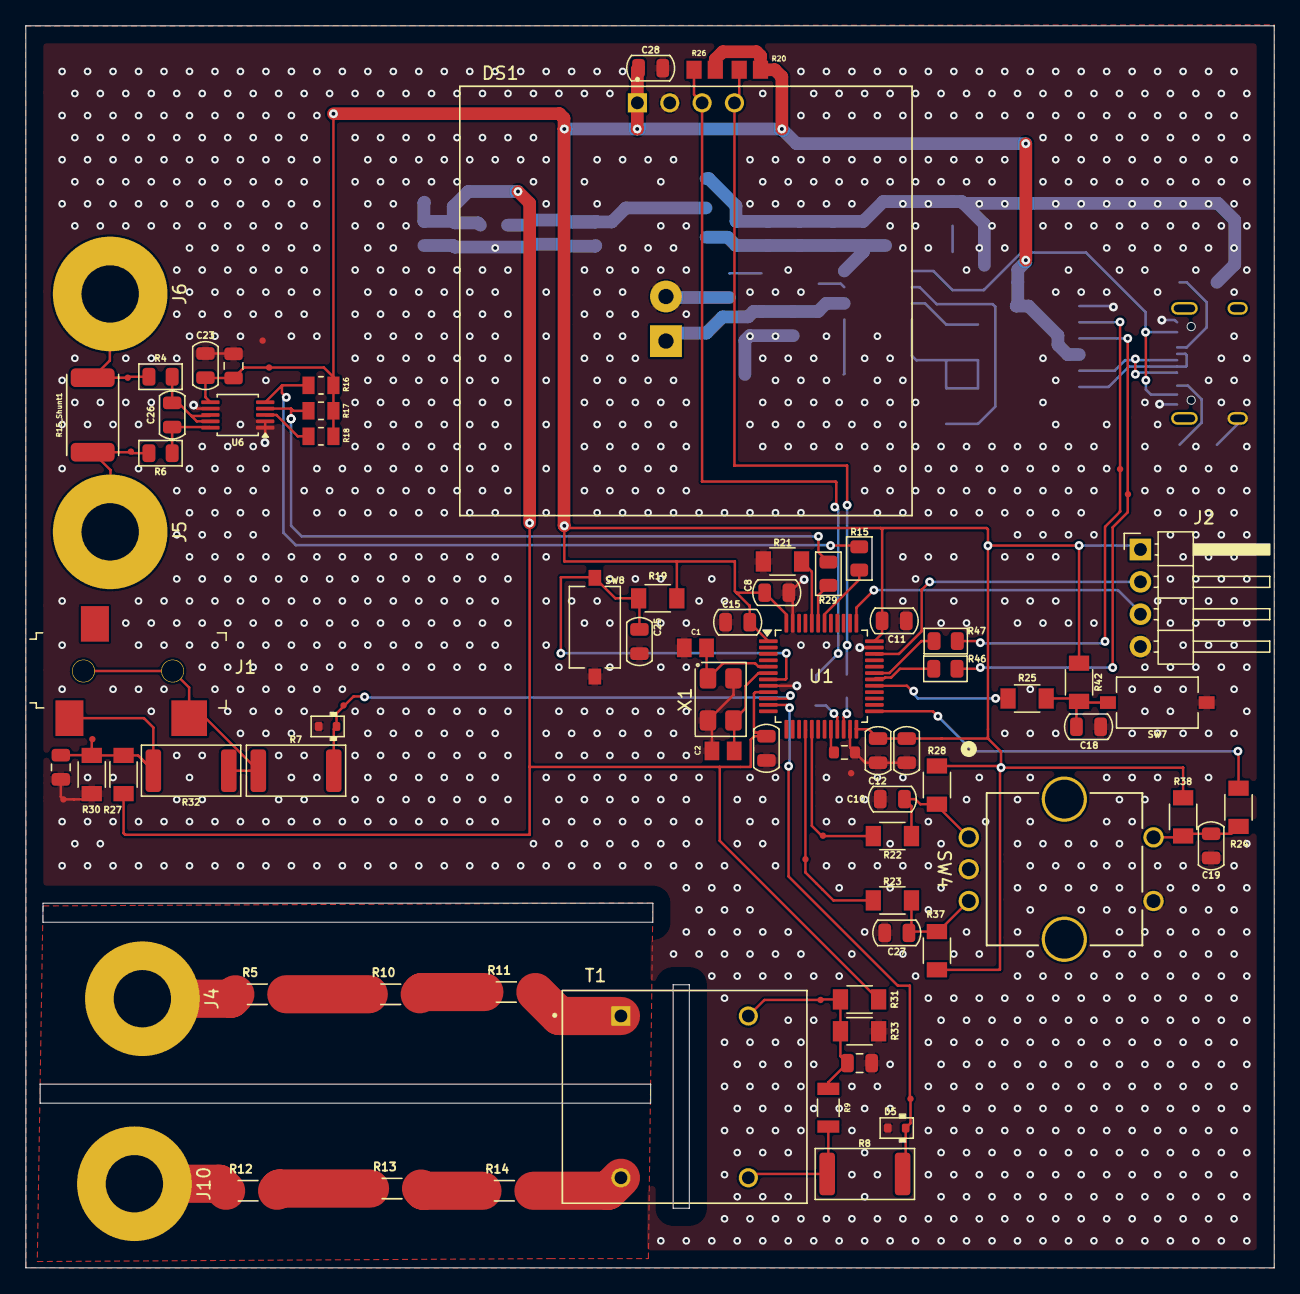
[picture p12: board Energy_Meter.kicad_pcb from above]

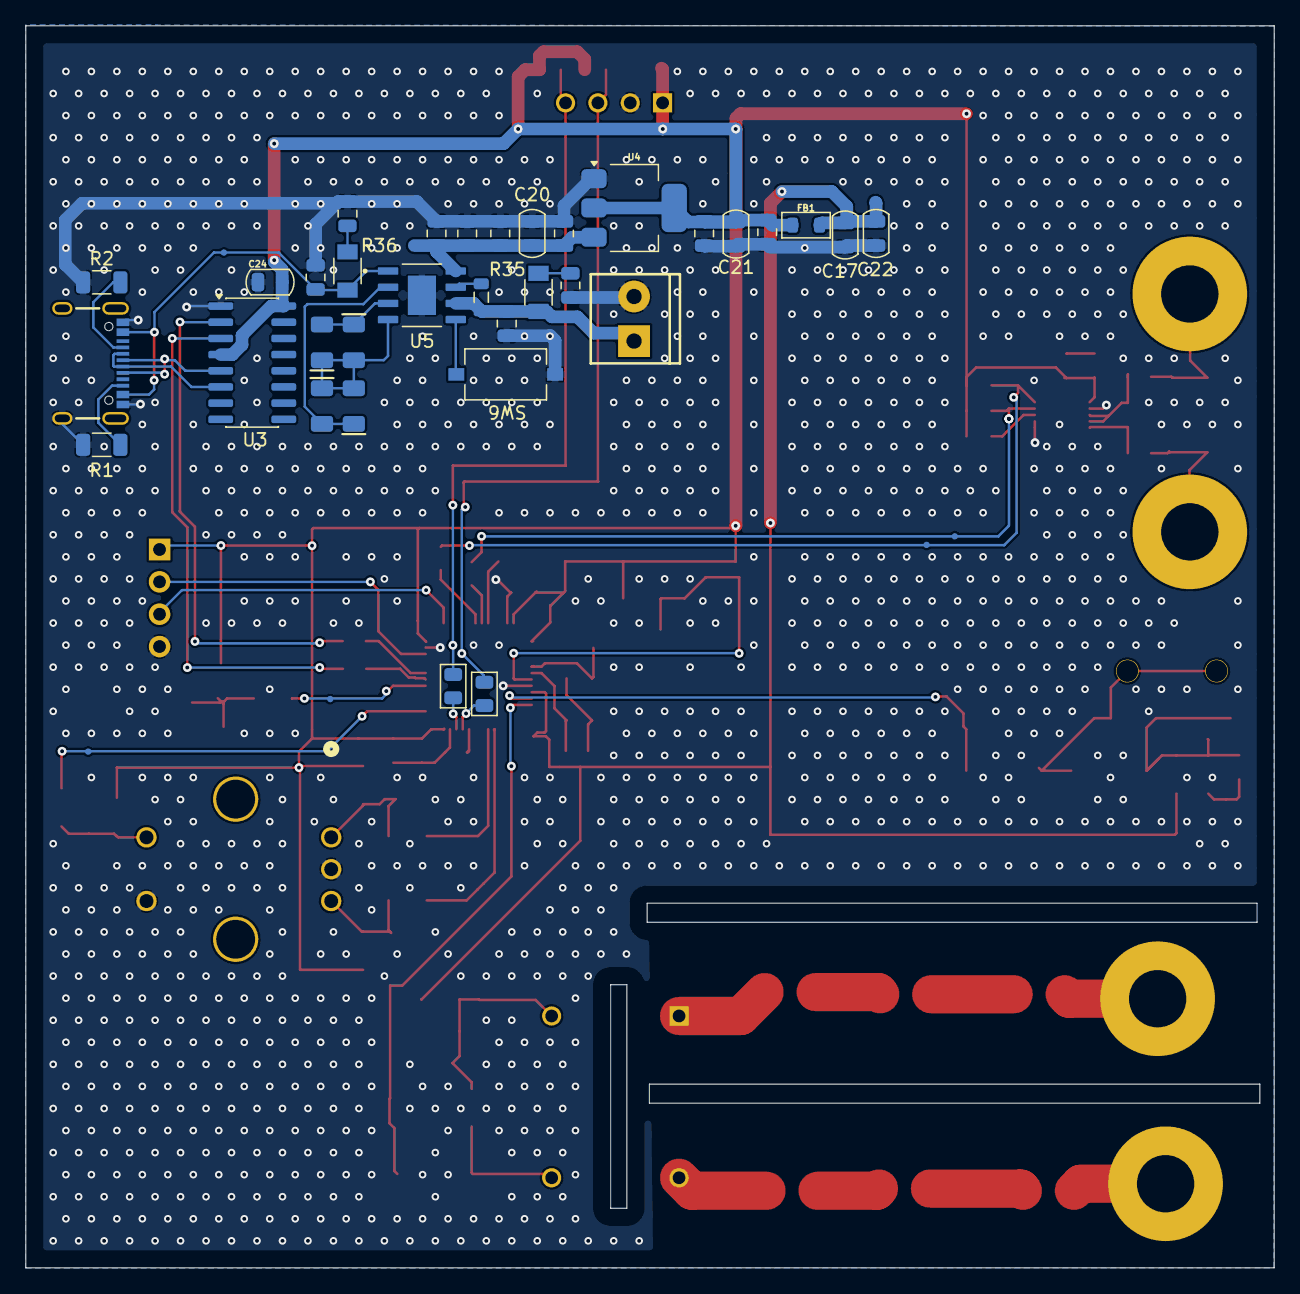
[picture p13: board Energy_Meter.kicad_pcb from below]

Board: 2 copper layers, 98.0 x 97.5 mm, 131 parts (42 on the bottom side), 63 nets.

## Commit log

2026-06-15 update 15/06/2026
    [Energy_Meter.kicad_pcb, Energy_Meter.kicad_sch]
2026-06-18 update 18/06/2026
    [Energy_Meter.kicad_sch]
2026-06-19 update 19/06/2026
    [Energy_Meter.recovered.2026-06-18_162926.kicad_sch]
2026-06-23 update 23/06/2026
    [Energy_Meter.recovered.2026-06-18_162926.kicad_sch]
2026-06-24 update 24/06/2026
    [Energy_Meter.csv, Energy_Meter.kicad_pcb, Energy_Meter.kicad_sch]
2026-06-26 update 26/06/2026
    [Energy_Meter.kicad_pcb, Energy_Meter.kicad_sch]
2026-06-30 update 30/06/2026
    [Energy_Meter.csv, Energy_Meter.kicad_pcb, Energy_Meter.kicad_sch]
2026-07-01 update 01/07/2026
    [Energy_Meter.csv, Energy_Meter.kicad_pcb, Energy_Meter.kicad_sch]
2026-07-02 update 02/07/2026
    [Energy_Meter.csv, Energy_Meter.kicad_pcb]
2026-07-15 update 15/07/2026
    [Energy_Meter.csv, Energy_Meter.kicad_pcb, Energy_Meter.kicad_sch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]
2026-07-16 update 16/07/2026
    [Energy_Meter.kicad_pcb, Energy_Meter.kicad_sch]
2026-07-17 update 17/07/2026
    [Energy_Meter.kicad_pcb]
2026-07-18 update 18/07/2026
    [Energy_Meter.kicad_pcb, Energy_Meter.kicad_sch]
2026-07-20 update 20/07/2026
    [Energy_Meter.kicad_pcb, Energy_Meter.kicad_sch]
2026-07-22 update 22/07/2026
    [Energy_Meter.csv, Energy_Meter.kicad_pcb, Energy_Meter.kicad_sch]
2026-07-27 update 27/07/2026
    [Energy_Meter-B_Cu.gbl, Energy_Meter-B_Mask.gbs, Energy_Meter-B_Paste.gbp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]
2026-07-29 update 29/07/2026
    [Energy_Meter-B_Cu.gbr, Energy_Meter-B_Mask.gbr, Energy_Meter-B_Paste.gbr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]
2026-08-29 update 29/08/2026
    [Energy_Meter.kicad_pcb, Energy_Meter.kicad_sch]
